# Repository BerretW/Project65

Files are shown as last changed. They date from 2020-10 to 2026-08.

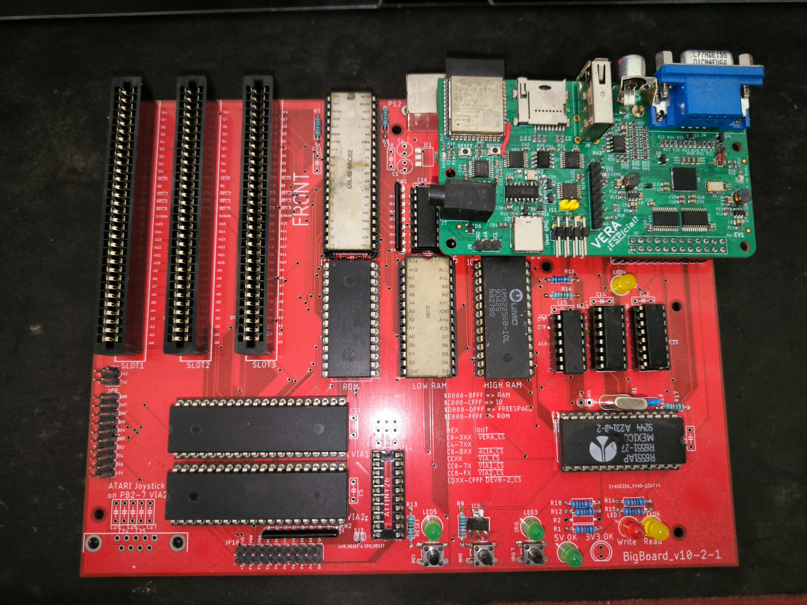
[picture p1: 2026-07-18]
images/V10-2-1_Vera2.jpg

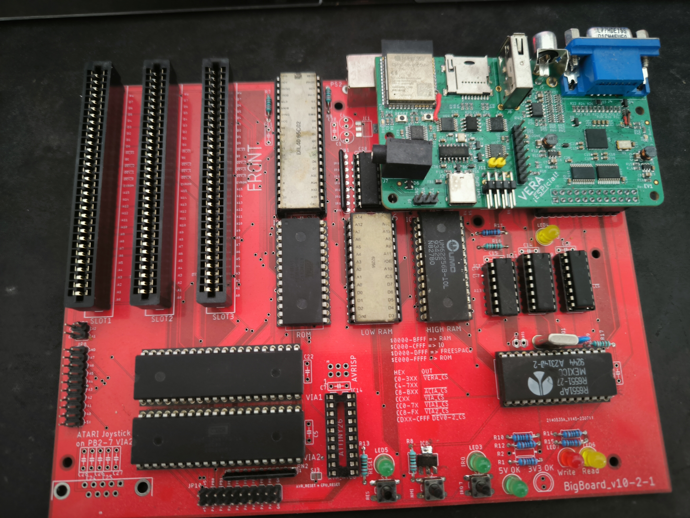
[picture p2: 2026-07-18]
images/V10-2-1_Vera.jpg

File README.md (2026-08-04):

# Project65 — SBC 65C02 IRQ BigBoard

A fully custom **W65C02-based single-board computer** featuring an 8-priority-level IRQ subsystem, three ISA-8 expansion slots, a PS/2 keyboard interface, RS-232 serial port, and a complete firmware stack — including an interactive OS with a RAM-disk filesystem. Accompanied by a **full-featured Rust emulator** with a terminal UI and an **FPGA VGA + audio controller** (`APARTS_BUS`) for Intel MAX 10.

---

## Features

- **CPU:** W65C02S @ up to 8 MHz (jumper-selectable from 32 MHz main oscillator)
- **Memory:** 64 KB total — 32 KB lower RAM + 32 KB upper RAM + 8 KB EEPROM ROM
- **Serial:** R6551 ACIA with a 1.8432 MHz crystal for accurate baud rates
- **Parallel I/O:** 2× W65C22S VIA controllers (keyboard polling + parallel port)
- **PS/2 Keyboard:** ATtiny26 co-processor bridge
- **Interrupt system:** 74HC148 priority encoder + 74HC574 latch — 8 prioritized IRQ lines + NMI
- **Expansion:** 3× ISA-8 slots (TMS9918A, GameDuino, APARTS_BUS FPGA card)
- **FPGA video/audio:** `APARTS_BUS` — VGA 640×480, external SRAM framebuffer, font RAM, 4-ch DDS/ADSR → PCM5102A I²S
- **Firmware:** Two build targets — minimal bootloader and full AppartusOS
- **Emulator:** Rust TUI emulator (`p65emu`) with cycle-accurate peripherals

---

## Repository Structure

```text
Project65/
├── Eagle/              # PCB schematics and board layouts (Eagle CAD)
│   ├── SBC_65C02_IRQ_BigBoard_v10-2-1.*
│   ├── EXP_TMS9918A_V1.*
│   └── EXP_GameDuino_V1.*
├── Firmware/           # 65C02 firmware (cc65 / ca65 toolchain)
│   ├── src/            # Assembly + C sources (drivers, OS, shell, EWOZ)
│   │   └── os/         # AppartusOS modules
│   ├── config/         # ld65 linker configurations
│   ├── output/         # Build artifacts (*.bin, *.map)
│   ├── build_minimal.bat
│   └── build_appartus.bat
├── emulator/           # Rust emulator (p65emu)
│   └── src/            # cpu, bus, ram, rom, acia, via, irq_latch, tui
├── aprts_vga/          # APARTS_BUS FPGA RTL (Verilog) + Quartus + sim
│   ├── aprts_bus.v     # Top-level 6502 bus interface
│   ├── vga_timing.v    # VGA 640×480 @ 60 Hz timing (25 MHz)
│   ├── vga_video_gen.v # Graphics/text pixel path + font RAM
│   ├── sram_controller.v
│   ├── aprts_audio.v   # 4-ch DDS/ADSR + I²S (PCM5102A)
│   ├── 10M02_test.qsf  # Quartus project (MAX 10 10M02SCE144C8G)
│   └── sim/            # ModelSim / Icarus testbenches
├── GAL/                # Glue logic (PLD)
├── tools/
│   ├── uploader.py     # Python/tkinter firmware uploader (COM or TCP)
│   ├── aprts_vga/      # 6502 demo for FPGA VGA
│   ├── audio/          # Audio driver + samples (ca65)
│   └── …               # hello, mem_mon, vera_test, vga_test, …
└── CLAUDE.md           # Full hardware reference (address map, ICs, bugs)
```

---

## Hardware Overview

| Reference | Part | Description |
| --- | ---- | --- |
| IC4 | W65C02SP | Main CPU (CMOS 65C02, DIP-40) |
| IC5 | AT28C64B | 8 KB EEPROM — ROM (`$E000–$FFFF`) |
| IC6 | 62256 | 32 KB SRAM — lower RAM (`$0000–$7FFF`) |
| IC7 | 62256 | 32 KB SRAM — upper RAM (`$8000–$BFFF`) |
| IC8 | DS1233 | Power-on reset supervisor |
| IC16 | W65C22S6TP | VIA #2 (`$CC80`) — parallel port JP8, generates **IRQ1** |
| IC18 | W65C22S6TP | VIA #1 (`$CC00`) — ATtiny26 keyboard bridge, generates **NMI** |
| IC19 | R6551 | ACIA serial (`$C800–$CBFF`) |
| IC14 | ATtiny26 | PS/2 keyboard co-processor (PB3=CLK, PB4=DATA) |
| U$1 | MCP2221A | USB-C ↔ UART/I²C bridge |
| IC9/IC11 | 74HCT139N | Two-stage address decoder |
| IC17 | 74HC148N | 8→3 priority IRQ encoder |
| IC27 | 74HC574N | IRQ status latch (readable at `$C480`) |
| QG1 | 32 MHz | Main system oscillator |
| Q1 | 1.8432 MHz | ACIA baud-rate crystal |
| X1–X3 | ISA-8 slots | Three 8-bit ISA expansion slots |

### ISA Expansion Cards

| Card | Description |
| ---- | --- |
| `EXP_TMS9918A_V1` | TMS9918A video card |
| `EXP_GameDuino_V1` | GameDuino graphics card |
| **APARTS_BUS** (`aprts_vga/`) | FPGA VGA 640×480 + external SRAM + 4-ch audio (MAX 10) |

---

## Address Map

```text
$0000–$7FFF   IC6 SRAM — lower 32 KB       (!CS = A15 low)
$8000–$BFFF   IC7 SRAM — upper 32 KB       (!CS = !HRAM_CS)
$C000–$C3FF   VERA / ISA video             (!VERA_CS)
$C400–$C7FF   IRQ latch                    read $C480–$C4FF / ack $C400–$C47F
$C800–$CBFF   ACIA R6551
$CC00–$CC7F   VIA1 (IC18) — keyboard/NMI
$CC80–$CCFF   VIA2 (IC16) — parallel/IRQ1
$CD00–$CDFF   ISA DEV0
$CE00–$CEFF   ISA DEV1
$CF00–$CFFF   ISA DEV2   ← typical APARTS_BUS decode (tools use $CF00 / $CE00)
$D000–$DFFF   ISA extended
$E000–$FFFF   EEPROM ROM (8 KB)
```

### IRQ Priority Table

| Level | Signal | Source |
| ----- | --- | --- |
| 0 (highest) | IRQ0 | R6551 ACIA |
| 1 | IRQ1 | VIA2 (IC16, `$CC80`) |
| 2–6 | IRQ2–6 | ISA slots |
| 7 (lowest) | IRQ7 | Button S1 |
| — | **NMI** | **VIA1 (IC18, `$CC00`)** |

---

## APARTS_BUS — FPGA VGA & Audio (`aprts_vga/`)

RTL controller for the 6502/ISA bus: **VGA output**, **external SRAM framebuffer (up to 512 KB / 19-bit address)**, **internal font RAM**, and a **4-channel synthesizer** driving a **PCM5102A** over I²S.

Detailed programmer manual: [`aprts_vga/README.md`](aprts_vga/README.md).

### Target & RTL modules

| Item | Value |
| ---- | ----- |
| FPGA | Intel **MAX 10** — `10M02SCE144C8G` |
| Quartus project | `aprts_vga/10M02_test.qsf` |
| Top entity | `aprts_bus` |
| Pixel clock | **25 MHz** — VGA **640×480 @ 60 Hz** |

| File | Module | Role |
| ---- | --- | ---- |
| `aprts_bus.v` | `aprts_bus` | Top: 4-bit port decode, CPU R/W, submodule wiring |
| `vga_timing.v` | `vga_timing` | H/V counters, HSYNC/VSYNC, `video_on` |
| `vga_video_gen.v` | `vga_video_gen` | Graphics/text RGB, font RAM (128×8 = 1024 B), cursor blink |
| `sram_controller.v` | `sram_controller` | CPU ↔ VGA arbiter, hardware clear engine |
| `aprts_audio.v` | `aprts_audio` | 4-ch DDS + ADSR, I²S (`pcm_bck` / `pcm_din` / `pcm_lrck`) |

### External interfaces (from `aprts_bus`)

```text
6502 bus:   n_reset, n_mem_w, n_mem_r, lv_cs, clk, lv_addr[3:0], lv_data[7:0]
VGA:        red[2:0], green[2:0], blue[2:0], hsync, vsync
SRAM:       sram_addr[18:0], sram_data[7:0], sram_ce_n, sram_oe_n, sram_we_n
Audio I²S:  pcm_bck, pcm_din, pcm_lrck, pcm_sck
```

### Register map (ports `$0`–`$F` relative to card base)

| Port | Write | Read |
| ---- | ----- | ---- |
| `$0` | Background color RGB332 | `reg_bg_color` |
| `$1` | Address / cursor hi (`addr_hi`) | same |
| `$2` | Address mid (`addr_mid`) | same |
| `$3` | Address lo (`addr_lo`) | same |
| `$4` | Data → SRAM / font / text cell | Data ← SRAM / font |
| `$5` | Audio register index (`0x00`–`0x17`) | current index |
| `$6` | Audio register data (index auto-inc) | selected audio reg |
| `$D` | Mode | current mode |
| `$F` | Start SRAM clear (any value) | status: bit0 = `addr_ready` |

CPU SRAM pointer is 19-bit: `{addr_hi[2:0], addr_mid, addr_lo}`. After each write to port `$4` (except font mode `$0D`) the address **auto-increments**.

**Background / pixel color:** `[7:5]` R, `[4:2]` G, `[1:0]` B (expanded to 3 bits in HW).

### Mode register (`$D`)

| Value | Behavior |
| ----- | --- |
| `$00`–`$0C` | Graphics — linear framebuffer from external SRAM |
| `$01` | Text 80×60, static cursor |
| `$02` | Text 80×60, blinking cursor (~2 Hz) |
| `$0D` | Font edit — R/W internal `font_mem` via port `$4` |
| `$0E` | Hardware logic reset (counters, audio, registers) |
| `$0F` | Blank screen (force black) |

Text buffer uses the first **4800** bytes of SRAM (`80×60`, `$0000`–`$12BF`). Font RAM: **128 characters × 8 rows**.

### SRAM clear & status (`$F`)

- **Write:** starts hardware fill of external SRAM with zeros (clear range through `$4AFFF` in RTL).
- **Read bit 0 (`addr_ready`):** `1` = ready for CPU access; `0` = clear/write busy. Poll before further writes.

### Audio (ports `$5` / `$6`)

Four independent DDS channels mixed to I²S (PCM5102A). Sample rate in driver notes: **~48.828 kHz**.

Per channel (base offsets for ch0; +3 per channel for ch1–3):

| Index | Register |
| ----- | --- |
| `+0` / `+1` | Frequency lo / hi |
| `+2` | Volume |
| `$0C`–`$0F` | Control: wave `[2:0]`, ADSR enable `[3]`, gate/note-on `[4]` |
| `$10`–`$17` | ADSR Attack/Decay and Sustain/Release pairs |

Waveforms: `0` square, `1` triangle, `2` saw, `3` sine, `4` trapezoid. Writing `$6` auto-increments the audio index.

### Simulation (`aprts_vga/sim/`)

| File | Purpose |
| ---- | --- |
| `tb_aprts_bus.v` | Integration test of full `aprts_bus` |
| `tb_vga_timing.v` | VGA timing unit test |
| `tb_aprts_audio.v` | Audio registers + I²S clocks |
| `sram_model.v` | Behavioral 512 KB SRAM |
| `run_msim.bat` / `run_msim.do` | ModelSim / Questa-Intel |
| `run_iverilog.bat` | Icarus Verilog |

```bat
cd aprts_vga\sim
run_msim.bat
rem or: run_iverilog.bat
```

See [`aprts_vga/sim/README.md`](aprts_vga/sim/README.md).

### Host-side tools

| Path | Description |
| ---- | --- |
| `tools/aprts_vga/` | ca65 demo (`demo.asm`) — base often `$CF00` |
| `tools/audio/` | Audio includes (`audio.inc65`) and samples — ports `$5`/`$6` on card base |

Exact ISA slot base (`$CD00` / `$CE00` / `$CF00`) depends on which DEV chip-select the card is wired to.

---

## Firmware

### Prerequisites

- [cc65](https://cc65.github.io/) toolchain (`cc65`, `ca65`, `ld65`) on `PATH`

### Minimal Build

ACIA serial + EWOZ (WozMon) monitor + serial bootloader (loads to `$6000`).  
No keyboard, VDP, SPI, SD, GameDuino, or SAA1099 dependencies.

```bat
cd Firmware
build_minimal.bat
```

Output: `Firmware/output/MIN_ROM.bin` (8 KB, write to EEPROM IC5)

### AppartusOS Build

Full OS: ACIA + EWOZ (`MON` command) + Intel HEX loader + interactive shell + RAM-disk FS.

```bat
cd Firmware
build_appartus.bat
```

Output: `Firmware/output/APPARTUS_OS.bin` (8 KB, write to EEPROM IC5)

### AppartusOS Shell Commands

```text
HELP / ?                   — help
VER                        — OS version
DIR                        — list RAM-disk files
FREE                       — show free space
FORMAT                     — reinitialize RAM disk (requires Y confirmation)
LOAD                       — receive Intel HEX via ACIA
SAVE <name> <addr> <size>  — save RAM region to RAM disk (hex addresses)
DEL  <name>                — delete file
RUN  <name>                — execute file (program can RTS back to shell)
MON                        — EWOZ / WozMon monitor
RESET                      — soft reset ($FF00)
```

### RAM Disk Layout (`$6000–$BFFF`, 24 KB)

```text
$6000–$600F   Header: "APOS" + num_files + free_ptr
$6010–$610F   Directory: 16 entries × 16 bytes
              +0 name[8]  +8 load_addr  +10 size  +12 flags  +13 stor_addr
$6110–$BFFF   File data (~24 KB usable)
```

### Firmware Memory Map (ROM, `$E000–$FFFF`)

```text
ZP:      $0000–$00FF   (zero page; cc65 $00–$1F, EWOZ $24–$30, ihex $38–$3E, OS $40–$4E)
RAM:     $0200–$5FFF   (working RAM; stack at $5FFF growing down)
ROM:     $E000–$FFFF   (EEPROM, fill $FF)
JMPTBL:  $FF00         (BIOS-style jump table)
VECTORS: $FFFA         (NMI / RESET / IRQ vectors)
```

---

## Emulator — p65emu

A cycle-accurate Rust emulator with a ratatui terminal UI.

### Build Requirements

- [Rust toolchain](https://rustup.rs/) (stable)

### Build & Run

```sh
cargo run --manifest-path emulator/Cargo.toml -- [ROM.bin] [-s SPEED_HZ] [-p TCP_PORT]
```

| Flag | Default | Description |
| ---- | --- | --- |
| `ROM.bin` | — | ROM image to load at `$E000` |
| `-s SPEED_HZ` | `1000000` | Emulation speed in Hz |
| `-p TCP_PORT` | `6551` | TCP serial port (0 = disabled) |
| `--family` | `HCT` | Logic family timing model (`LS`, `ALS`, `HCT`, `HC`, `AC`, `ACT`) |

### Emulated Components

| Module | Hardware |
| --- | --- |
| `cpu.rs` | W65C02 — fetch/decode/execute + NMI/IRQ |
| `ram.rs` | IC6 + IC7 SRAM |
| `rom.rs` | 8 KB EEPROM |
| `acia.rs` | R6551 — TX/RX queues shared with TUI and TCP |
| `via.rs` | VIA1 (`$CC00`) + VIA2 (`$CC80`) — T1/T2 timers |
| `irq_latch.rs` | 74HC574 latch + 74HC148 encoder |
| `tms9918a.rs` | TMS9918A video (minifb window) |
| `saa1099.rs` | SAA1099 audio (rodio) |

### TUI Keyboard Shortcuts

| Key | Action |
| --- | --- |
| F2 | Single step |
| F3 | Run / Pause |
| F4 | Reset CPU |
| F5–F9 | Speed: 1K / 10K / 100K / 1M / MAX Hz |
| +/- | Speed ×2 / ÷2 |
| Tab | Memory view: ZP / RAM / HiRAM / I/O / ROM / Addr |
| Shift+Tab | Right panel: CPU / VIA1 / VIA2 / ACIA / IRQ |
| PgUp/PgDn | Scroll memory |
| Shift+Pg | Scroll terminal |
| Ctrl+O | File browser — load ROM or RAM image |
| Ctrl+G | Jump to hex address in memory dump |
| Ctrl+M | Edit byte at address |
| Ctrl+R | Edit CPU registers (A/X/Y/SP/PC/P) |
| F10 / Ctrl+Q | Quit |

The TCP serial port (default `127.0.0.1:6551`) allows PuTTY, netcat, or `uploader.py` to connect as if it were real hardware.

---

## Tools

### tools/uploader.py

Python/tkinter GUI for uploading firmware to the real board or the emulator.

**Dependencies:**

```sh
pip install pyserial
```

**Connection modes:**

- **COM port** — real hardware (19200 Bd, 8N1)
- **TCP** — emulator (`127.0.0.1:6551`)

**Bootloader protocol:**

| Command | Action |
| --- | --- |
| `w` | Raw binary upload — exactly 8192 bytes → `$6000–$7FFF` |
| `h` | Intel HEX upload (any address) |
| `s` | Jump to `$6000` (run program) |
| `m` | Enter EWOZ / WozMon monitor |
| `^R` (`$12`) | Soft-restart bootloader |

### Other tools

| Path | Description |
| ---- | --- |
| `tools/aprts_vga/` | APARTS_BUS VGA demo for AppartusOS |
| `tools/audio/` | 4-channel FPGA audio driver and samples |
| `tools/hello/` | Sample user program |
| `tools/ihex_gen.py` | Intel HEX helper |
| `tools/espi_update_fpga.py` | FPGA update helper |
| `tools/vera_test/`, `tools/vga_test/` | Video experiments |

---

## Typical Workflow

```sh
# 1. Build firmware
cd Firmware && build_appartus.bat

# 2. Start emulator
cargo run --manifest-path emulator/Cargo.toml -- Firmware/output/APPARTUS_OS.bin

# 3. In emulator terminal — send a program via Intel HEX
> LOAD
  (paste or send .hex file via uploader.py over TCP)

# 4. Save and run
> SAVE HELLO 6090 0100
> DIR
> RUN HELLO
```

FPGA RTL / sim workflow:

```bat
cd aprts_vga\sim
run_msim.bat
```

---

## Known Issues

| # | Status | Description |
| - | --- | --- |
| 1 | ✅ Fixed | `_nmi_init` in `utils.asm` — NMI Timer1 initialization correctly configures VIA1 (IC18) at $CC00 |
| 2 | ✅ Fixed | NMI ISR correctly reloads VIA1 (IC18) T1 counter — verified in `interrupts.asm:19` |
| 3 | ✅ Fixed | PS/2 keyboard driver in `pckybd.asm:25–28` — now correctly reads from VIA1 (IC18, ATtiny26) |
| 4 | ✅ Fixed | `VDP_MODE0 = $C000` — correctly placed in ISA I/O space, no longer conflicts with IC6 RAM |

All critical hardware bugs have been resolved.

---

## Hardware Files

| File | Description |
| ---- | --- |
| `Eagle/SBC_65C02_IRQ_BigBoard_v10-2-1.csv` | Current BOM / netlist |
| `Eagle/SBC_65C02_IRQ_BigBoard_v9-1-3.sch` | Main schematic (Eagle) |
| `Eagle/SBC_65C02_IRQ_BigBoard_v9-1-3.brd` | Main PCB layout (Eagle) |
| `Eagle/EXP_TMS9918A_V1.sch/.brd` | TMS9918A ISA video card |
| `Eagle/EXP_GameDuino_V1.sch/.brd` | GameDuino ISA graphics card |
| `aprts_vga/*.v` | APARTS_BUS FPGA RTL (VGA + SRAM + audio) |
| `aprts_vga/10M02_test.qsf` | Quartus pinout / project for MAX 10 |

Full hardware documentation (address decoding logic, IC cross-reference, IRQ system) is in [`CLAUDE.md`](CLAUDE.md).  
FPGA register-level docs: [`aprts_vga/README.md`](aprts_vga/README.md).

---

## License

See [`Firmware/LICENSE`](Firmware/LICENSE).

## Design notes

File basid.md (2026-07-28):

# P65 BASIC — syntax a manuál

Tento dokument popisuje syntaxi a chování BASICu implementovaného v [Firmware/src/os/appartus_basic.asm](Firmware/src/os/appartus_basic.asm).

## 1. Co je to za BASIC?

P65 BASIC je minimalistický line-oriented BASIC pro Project65 SBC.

- pracuje s celými čísly, 16bitovými a znaménkovými
- používá proměnné A až Z
- program je ukládán do paměti RAM jako seznam řádků
- podporuje direktivní příkazy i programové příkazy

## 2. Základní pravidla

### 2.1 Čísla

- desetinná čísla nejsou podporována
- všechny hodnoty jsou 16-bitové signed integery
- záporná čísla jsou podporována
- hexadecimální konstanta se zapisuje s předponou `$`

Příklady:

- `10`
- `-5`
- `$1F`
- `$FF00`

### 2.2 Proměnné

Proměnné jsou pojmenovány jedním písmenem `A` až `Z`.

Příklady:

- `A = 10`
- `B = A + 5`

### 2.3 Programové řádky

Každý řádek programu začíná číslem řádku:

```basic
10 PRINT "Ahoj"
20 END
```

Řádkové číslo může být zadáno jako desetinné číslo nebo hexadecimální konstanta.

## 3. Direktivní příkazy

Tyto příkazy se spouštějí přímo z promptu, nikoli jako programové řádky.

### 3.1 NEW

Smaže celý program.

```basic
NEW
```

### 3.2 LIST

Vypíše uložený program.

```basic
LIST
```

### 3.3 RUN

Spustí program od prvního řádku.

```basic
RUN
```

### 3.4 SAVE

Uloží program do RAMDisku pod jméno.

```basic
SAVE "HELLO"
```

- název může mít maximálně 8 znaků
- uložení se provádí do RAMDisku

### 3.5 LOAD

Načte program z RAMDisku.

```basic
LOAD "HELLO"
```

### 3.6 BYE

Vrátí se zpět do shellu OS.

```basic
BYE
```

## 4. Programové příkazy

### 4.1 REM

Komentář. Vše za `REM` je ignorováno.

```basic
10 REM Toto je komentář
20 PRINT 1
```

### 4.2 PRINT

Vypíše text nebo hodnotu výrazu.

```basic
10 PRINT "HELLO"
20 PRINT A
30 PRINT 10 + 5
```

Více položek lze oddělit znakem `;` nebo `,`.

```basic
10 PRINT "A=", A
20 PRINT 1; 2; 3
```

- `;` znamená bez nového řádku mezi položkami
- `,` vypíše mezery mezi položkami

### 4.3 INPUT

Načte vstup z konzole a uloží do proměnné.

```basic
10 INPUT A
```

Volitelně lze zadat prompt:

```basic
10 INPUT "Zadej cislo: ", A
```

### 4.4 Přiřazení

Podporováno je `LET` i implicitní přiřazení.

```basic
10 LET A = 10
20 B = A + 5
```

### 4.5 IF ... THEN

Podmínka se vyhodnotí a pokud je pravdivá, skočí na zadaný řádek.

```basic
10 IF A > 0 THEN 30
20 PRINT "NE"
30 PRINT "ANO"
```

Poznámka: `THEN` je nepovinný v implementaci, ale doporučený zápis je s ním.

### 4.6 FOR ... TO ... STEP ...

Smyčka s počítadlem.

```basic
10 FOR A = 1 TO 5
20 PRINT A
30 NEXT
```

Volitelný krok:

```basic
10 FOR A = 0 TO 10 STEP 2
20 PRINT A
30 NEXT
```

### 4.7 NEXT

Konec smyčky `FOR`.

```basic
10 FOR A = 1 TO 3
20 PRINT A
30 NEXT
```

### 4.8 WHILE ... WEND

Podmíněná smyčka.

```basic
10 A = 0
20 WHILE A < 3
30 PRINT A
40 A = A + 1
50 WEND
```

### 4.9 GOTO

Nepodmíněný skok na jiný řádek.

```basic
10 GOTO 30
20 PRINT "Tento řádek se nepřeskočí"
30 PRINT "Skok funguje"
```

### 4.10 GOSUB / RETURN

Volání podprogramu.

```basic
10 GOSUB 30
20 END
30 PRINT "Podprogram"
40 RETURN
```

### 4.11 END

Ukončí běh programu.

```basic
10 PRINT "Konec"
20 END
```

### 4.12 POKE

Zapíše hodnotu do paměti na zadanou adresu.

```basic
10 POKE 40960, 255
```

## 5. Výrazy

### 5.1 Operátory

Podporované operátory:

- `+` sčítání
- `-` odčítání / unární negace
- `*` násobení
- `/` dělení

### 5.2 Porovnání

Podporované porovnání:

- `=` rovnost
- `<>` nerovnost
- `<` menší
- `>` větší
- `<=` menší nebo rovno
- `>=` větší nebo rovno

Porovnání vrací `0` pro nepravdu a `1` pro pravdu.

### 5.3 Závorky

```basic
10 PRINT (2 + 3) * 4
```

### 5.4 PEEK

Načte bajt z paměti na dané adrese.

```basic
10 PRINT PEEK(1024)
```

Poznámka: `PEEK` vrací 8bitovou hodnotu a horní byte je nulový.

## 6. Priorita operátorů

Priorita je následující (od nejnižší po nejvyšší):

1. porovnání
2. `+` a `-`
3. `*` a `/`
4. unární `-` a primární výrazy

## 7. Chyby a hlášky

Při chybě BASIC vypíše jednu z těchto hlášek:

- `?SYNTAX ERROR` — špatný syntax
- `?UNDEFINED LINE` — neexistující řádek pro `GOTO`, `GOSUB`, `IF`
- `?FOR OVF` — přetečení zásobníku `FOR`
- `?NEXT WO FOR` — `NEXT` bez odpovídajícího `FOR`
- `?WHILE OVF` — přetečení zásobníku `WHILE`
- `?WEND WO WHILE` — `WEND` bez odpovídajícího `WHILE`
- `?GOSUB OVF` — přetečení zásobníku `GOSUB`
- `?RET WO GOSUB` — `RETURN` bez `GOSUB`
- `?DIV/0` — dělení nulou
- `?PROG FULL` — programová paměť je plná
- `?Save err.` — chyba při ukládání
- `?Not found.` — soubor nenalezen při `LOAD`

## 8. Příklad programu

```basic
10 REM Jednoduchý program
20 INPUT "Zadej cislo: ", A
30 IF A > 0 THEN 60
40 PRINT "Cislo je zaporne"
50 GOTO 70
60 PRINT "Cislo je kladne"
70 END
```

## 9. Praktické poznámky

- BASIC je určený pro jednoduché skripty a testování
- není to plnohodnotný moderní BASIC
- je vhodný pro práci s pamětí, jednoduchými rutinnami a obsluhou vstupu/výstupu
- programy jsou uloženy jako textové řádky s číslem řádku a nulovým terminátorem

## 10. Shrnutí

Nejčastější konstrukce jsou:

```basic
10 PRINT "Text"
20 INPUT A
30 IF A > 0 THEN 50
40 GOTO 60
50 FOR A = 1 TO 5
60 NEXT
70 WHILE A < 3
80 WEND
90 END
```

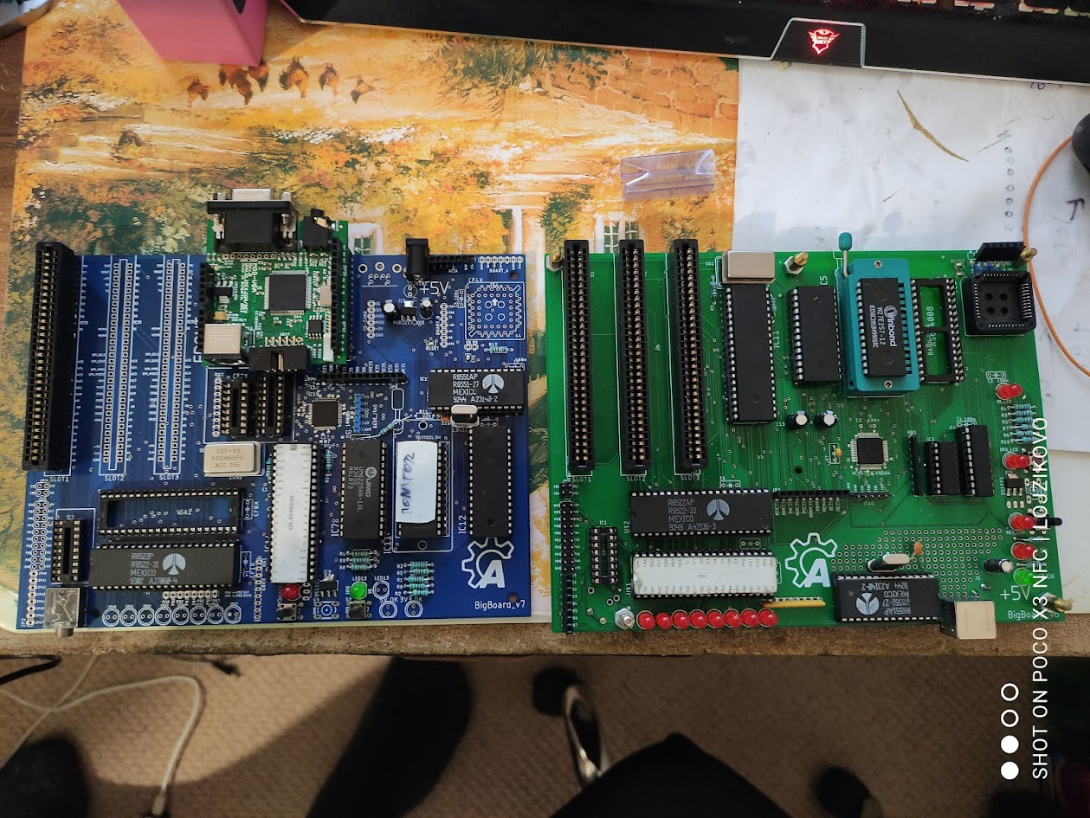
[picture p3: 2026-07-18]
images/V6_vs_V7.jpg

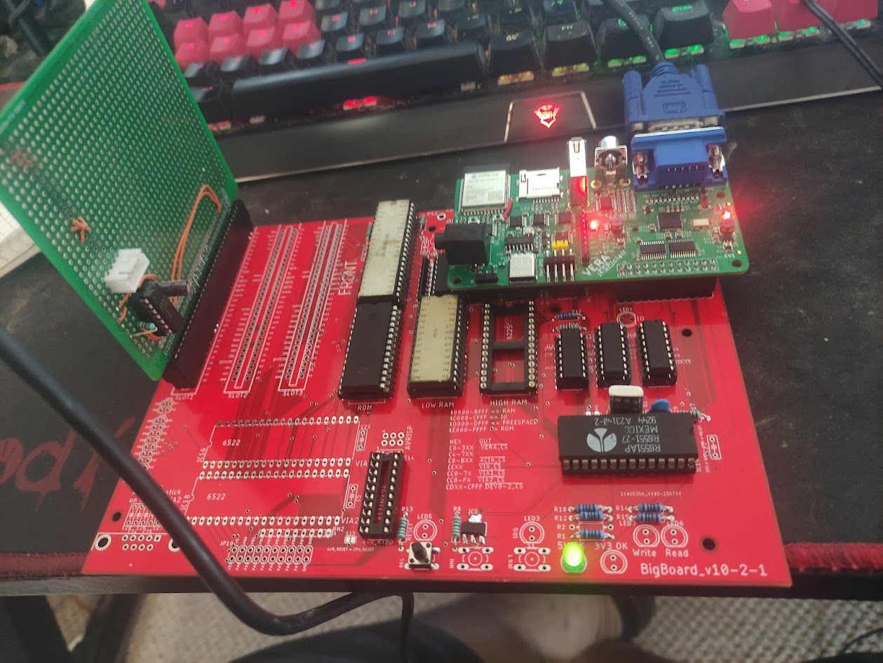
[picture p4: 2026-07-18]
images/V10-2-1_partial.jpg

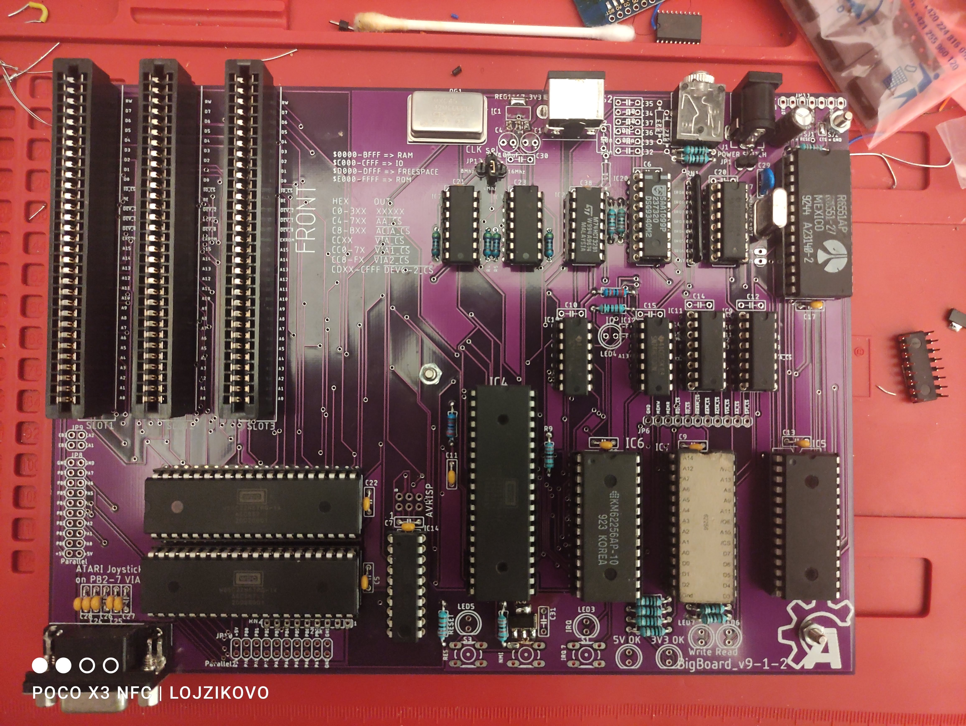
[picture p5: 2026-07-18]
images/V9-1-2.jpg

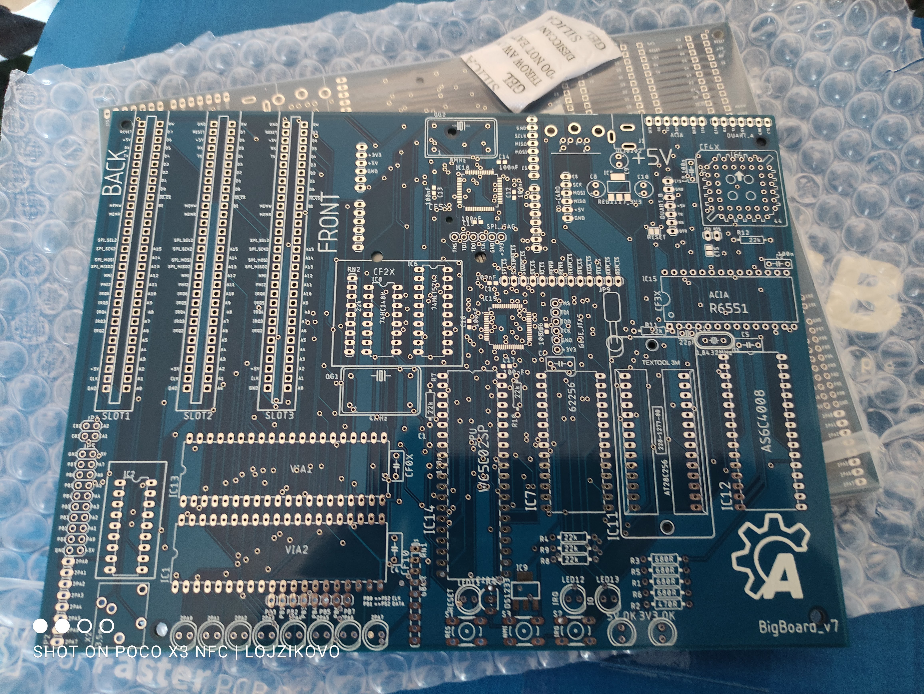
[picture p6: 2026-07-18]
images/V7_blank.jpg

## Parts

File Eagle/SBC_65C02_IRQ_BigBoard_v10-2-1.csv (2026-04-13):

Part | Value | Device | Package | Description | MF | MPN | OC_FARNELL | OC_NEWARK | POPULARITY | PROD_ID | SPICEPREFIX
C1 | 10uF | CPOL-EUE2.5-5 | E2,5-5 | POLARIZED CAPACITOR, European symbol |  |  |  |  | 16 |  | C
C2 |  | C-EU050-035X075 | C050-035X075 | CAPACITOR, European symbol |  |  |  |  | 2 |  | C
C3 |  | CPOL-EUE2.5-5 | E2,5-5 | POLARIZED CAPACITOR, European symbol |  |  |  |  | 16 |  | C
C4 | 100uF | CPOL-EUE2.5-5 | E2,5-5 | POLARIZED CAPACITOR, European symbol |  |  |  |  | 16 |  | C
C5 |  | C-EU050-025X075 | C050-025X075 | CAPACITOR, European symbol |  |  |  |  | 29 |  | C
C6 |  | C-EU050-025X075 | C050-025X075 | CAPACITOR, European symbol |  |  |  |  | 29 |  | C
C7 |  | C-EU050-025X075 | C050-025X075 | CAPACITOR, European symbol |  |  |  |  | 29 |  | C
C8 |  | C-EU050-025X075 | C050-025X075 | CAPACITOR, European symbol |  |  |  |  | 29 |  | C
C9 |  | C-EU050-025X075 | C050-025X075 | CAPACITOR, European symbol |  |  |  |  | 29 |  | C
C10 |  | C-EU050-025X075 | C050-025X075 | CAPACITOR, European symbol |  |  |  |  | 29 |  | C
C11 |  | C-EU050-025X075 | C050-025X075 | CAPACITOR, European symbol |  |  |  |  | 29 |  | C
C12 |  | C-EU050-025X075 | C050-025X075 | CAPACITOR, European symbol |  |  |  |  | 29 |  | C
C13 |  | C-EU050-025X075 | C050-025X075 | CAPACITOR, European symbol |  |  |  |  | 29 |  | C
C14 |  | C-EU050-025X075 | C050-025X075 | CAPACITOR, European symbol |  |  |  |  | 29 |  | C
C15 |  | C-EU050-025X075 | C050-025X075 | CAPACITOR, European symbol |  |  |  |  | 29 |  | C
C16 |  | C-EU050-025X075 | C050-025X075 | CAPACITOR, European symbol |  |  |  |  | 29 |  | C
C17 |  | C-EU050-025X075 | C050-025X075 | CAPACITOR, European symbol |  |  |  |  | 29 |  | C
C18 |  | C-EU050-025X075 | C050-025X075 | CAPACITOR, European symbol |  |  |  |  | 29 |  | C
C20 |  | C-EU050-025X075 | C050-025X075 | CAPACITOR, European symbol |  |  |  |  | 29 |  | C
C21 |  | C-EU050-025X075 | C050-025X075 | CAPACITOR, European symbol |  |  |  |  | 29 |  | C
C22 |  | C-EU050-025X075 | C050-025X075 | CAPACITOR, European symbol |  |  |  |  | 29 |  | C
C23 |  | C-EU050-025X075 | C050-025X075 | CAPACITOR, European symbol |  |  |  |  | 29 |  | C
C24 | 1n | C-EU050-025X075 | C050-025X075 | CAPACITOR, European symbol |  |  |  |  | 29 |  | C
C25 | 1n | C-EU050-025X075 | C050-025X075 | CAPACITOR, European symbol |  |  |  |  | 29 |  | C
C26 | 1n | C-EU050-025X075 | C050-025X075 | CAPACITOR, European symbol |  |  |  |  | 29 |  | C
C27 | 1n | C-EU050-025X075 | C050-025X075 | CAPACITOR, European symbol |  |  |  |  | 29 |  | C
C28 | 1n | C-EU050-025X075 | C050-025X075 | CAPACITOR, European symbol |  |  |  |  | 29 |  | C
C29 |  | C-EU050-025X075 | C050-025X075 | CAPACITOR, European symbol |  |  |  |  | 29 |  | C
C30 |  | C-EU050-025X075 | C050-025X075 | CAPACITOR, European symbol |  |  |  |  | 29 |  | C
C38 |  | C-EU050-025X075 | C050-025X075 | CAPACITOR, European symbol |  |  |  |  | 29 |  | C
IC1 | REG1117_3V3 | REG1117 | SOT223 | 800mA and 1A Low Dropout (LDO) Positive Regulator |  | REG1117 | 1097566 | 14P6981 | 49
IC2 | 74HC74N | 74HC74N | DIL14 | Dual D type positive edge triggered FLIP FLOP, preset and clear |  |  |  |  | 0
IC3 | 74HC74N | 74HC74N | DIL14 | Dual D type positive edge triggered FLIP FLOP, preset and clear |  |  |  |  | 0
IC4 | W65C02SP | W65C02SP | DIL40 | Western Digital Version
IC5 | 28C64AP | 28C64AP | DIL28-6 | CMOS EEPROM |  | AT28C64B-15PU | 1631144 | 96K6557 | 0
IC6 | 62256 | 62256P | DIL28-6 | MEMORY |  |  | unknown | unknown | 1
IC7 | 62256 | 62256P | DIL28-6 | MEMORY |  |  | unknown | unknown | 1
IC8 | DS1233 | DS1233SOT223 | SOT223
IC9 | 74HCT139N | 74HCT139N | DIL16 | Dual 2-line to 4-line DECODER/DEMULTIPLEXER |  |  |  |  | 0
IC10 | 74AC00N | 74AC00N | DIL14 | Quad 2-input NAND gate |  |  |  |  | 0
IC11 | 74HCT139N | 74HCT139N | DIL16 | Dual 2-line to 4-line DECODER/DEMULTIPLEXER |  |  |  |  | 0
IC12 | 74AC00N | 74AC00N | DIL14 | Quad 2-input NAND gate |  |  |  |  | 0
IC14 | ATTINY26-16PU | ATTINY26-16PU | DIL20 | 8-bit AVR tiny Microcontroller
IC16 | VIA1 | W65C22S6TP | DIL40 | W65C22 by WDC
IC17 | 74HC148N | 74HC148N | DIL16 | 10-line to 4-line and 8-line to 3-line PRIORITY ENCODER |  |  |  |  | 0
IC18 | VIA2 | W65C22S6TP | DIL40 | W65C22 by WDC
IC19 | R6551 | R6551 | DIP-28 | Rockwell R6551 ACIA
IC21 | 74AC32N | 74AC32N | DIL14 | Quad 2-input OR gate |  |  |  |  | 0
IC27 | 74HC574N | 74HC574N | DIL20 | 8-bit D type FLIP FLOP bus driver |  |  |  |  | 0
J1 | DCJ0202 | DCJ0202 | DCJ0202 | DC POWER JACK |  |  | unknown | unknown | 17
J2 | AVR_SPI_PROG_3X2NS | AVR_SPI_PROG_3X2NS | 2X3-NS | AVR ISP 6 Pin
J3 |  | DB9MALE | DB9_MALE | DB9 Connector |  |  |  |  |  | CONN-09904
J4 |  | USB_C2-LAYER | USB-C-16P | USB Type C 16Pin Connector |  |  |  |  |  | CONN-14122
JP1 |  | PINHD-1X2 | 1X02 | PIN HEADER |  |  |  |  | 98
JP2 |  | PINHD-1X1 | 1X01 | PIN HEADER |  |  |  |  | 64
JP3 |  | PINHD-1X1 | 1X01 | PIN HEADER |  |  |  |  | 64
JP4 |  | PINHD-1X1 | 1X01 | PIN HEADER |  |  |  |  | 64
JP5 |  | PINHD-1X1 | 1X01 | PIN HEADER |  |  |  |  | 64
JP6 |  | PINHD-2X12 | 2X12 | PIN HEADER |  |  |  |  | 3
JP8 | Parallel | PINHD-2X10 | 2X10 | PIN HEADER |  |  |  |  | 7
JP9 | Timer_OUT | PINHD-2X2 | 2X02 | PIN HEADER |  |  |  |  | 0
JP10 | Parallel2 | PINHD-2X10 | 2X10 | PIN HEADER |  |  |  |  | 7
JP11 |  | PINHD-1X7 | 1X07 | PIN HEADER |  |  |  |  | 0
JP12 |  | PINHD-1X2 | 1X02 | PIN HEADER |  |  |  |  | 98
JP13 |  | PINHD-1X1 | 1X01 | PIN HEADER |  |  |  |  | 64
LED1 |  | LED5MM | LED5MM | LED |  |  |  |  | 93
LED2 |  | LED5MM | LED5MM | LED |  |  |  |  | 93
LED3 |  | LED5MM | LED5MM | LED |  |  |  |  | 93
LED4 |  | LED5MM | LED5MM | LED |  |  |  |  | 93
LED5 |  | LED5MM | LED5MM | LED |  |  |  |  | 93
LED6 |  | LED5MM | LED5MM | LED |  |  |  |  | 93
LED7 |  | LED5MM | LED5MM | LED |  |  |  |  | 93
Q1 | 1,8432MHz | CRYSTALHC49S | HC49/S | CRYSTAL |  |  | 1667008 | unknown | 49
QG1 | 32Mhz | QG5860 | DIL14S | CRYSTAL RESONATOR |  |  | unknown | unknown | 0
R1 | 680R | R-EU_0207/10 | 0207/10 | RESISTOR, European symbol
R2 | 470R | R-EU_0207/10 | 0207/10 | RESISTOR, European symbol
R3 | 4k7 | R-EU_0204/7 | 0204/7 | RESISTOR, European symbol |  |  |  |  | 79 |  | R
R4 | 4k7 | R-EU_0204/7 | 0204/7 | RESISTOR, European symbol |  |  |  |  | 79 |  | R
R5 | 4k7 | R-EU_0204/7 | 0204/7 | RESISTOR, European symbol |  |  |  |  | 79 |  | R
R6 | 4k7 | R-EU_0204/7 | 0204/7 | RESISTOR, European symbol |  |  |  |  | 79 |  | R
R7 | 22k | R-EU_0207/10 | 0207/10 | RESISTOR, European symbol
R8 | 22k | R-EU_0207/10 | 0207/10 | RESISTOR, European symbol
R9 | 22k | R-EU_0207/10 | 0207/10 | RESISTOR, European symbol
R10 | 680R | R-EU_0207/10 | 0207/10 | RESISTOR, European symbol
R11 | 680R | R-EU_0207/10 | 0207/10 | RESISTOR, European symbol
R12 | 680R | R-EU_0207/10 | 0207/10 | RESISTOR, European symbol
R13 | 22k | R-EU_0207/10 | 0207/10 | RESISTOR, European symbol
R14 | 680R | R-EU_0207/10 | 0207/10 | RESISTOR, European symbol |  |  |  |  | 81 |  | R
R15 | 680R | R-EU_0207/10 | 0207/10 | RESISTOR, European symbol |  |  |  |  | 81 |  | R
R16 | 22K | R-EU_0207/10 | 0207/10 | RESISTOR, European symbol |  |  |  |  | 81 |  | R
R17 | 22k | R-EU_0207/10 | 0207/10 | RESISTOR, European symbol |  |  |  |  | 81 |  | R
RN1 | 22k | G08R | SIL9 | SIL RESISTOR |  |  | unknown | unknown | 6
RN2 | 22k | G08R | SIL9 | SIL RESISTOR |  |  | unknown | unknown | 6
S1 |  | 10-XX | B3F-10XX | OMRON SWITCH |  | B3F-1000 | 176432 | 36M3542 | 72
S2 |  | 10-XX | B3F-10XX | OMRON SWITCH |  | B3F-1000 | 176432 | 36M3542 | 72
S3 |  | 10-XX | B3F-10XX | OMRON SWITCH |  | B3F-1000 | 176432 | 36M3542 | 72
SJ1 |  | SJ | SJ | SMD solder JUMPER |  |  |  |  | 33
SJ2 |  | SJ | SJ | SMD solder JUMPER |  |  |  |  | 33
SJ3 |  | SJ | SJ | SMD solder JUMPER |  |  |  |  | 33
SJ4 |  | SJ | SJ | SMD solder JUMPER |  |  |  |  | 33
U$1 | MCP2221A-I/P | MCP2221A-I/P | DIL14
X1 |  | ISA-SLOT | ISA-8 | ISA SLOT
X2 |  | ISA-SLOT | ISA-8 | ISA SLOT
X3 |  | ISA-SLOT | ISA-8 | ISA SLOT
X4 |  | MINI_DIN_6 | M_DIN6

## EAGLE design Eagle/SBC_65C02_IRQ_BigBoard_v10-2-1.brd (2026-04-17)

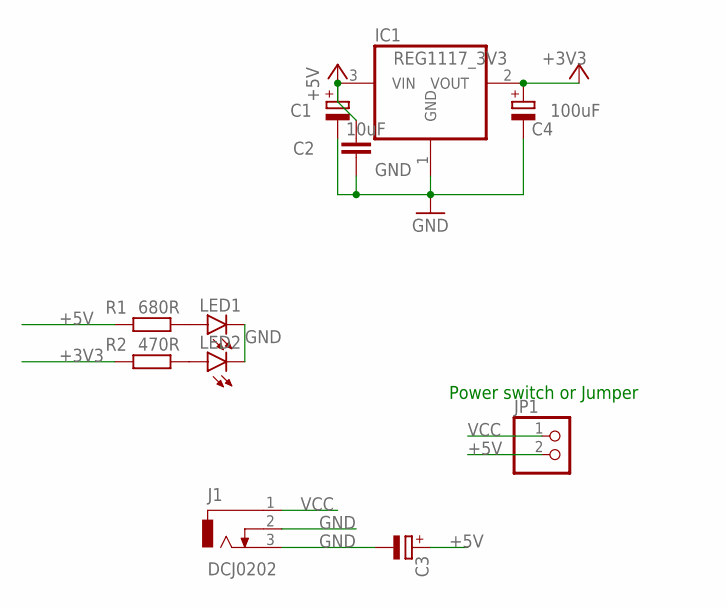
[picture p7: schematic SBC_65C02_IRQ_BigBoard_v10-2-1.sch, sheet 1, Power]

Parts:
C1: 10uF; E2,5-5
C2: C-EU050-035X075; C050-035X075
C3: CPOL-EUE2.5-5; E2,5-5
C4: 100uF; E2,5-5
IC1: REG1117_3V3; SOT223
J1: DCJ0202
JP1: PINHD-1X2; 1X02
LED1, LED2: LED5MM
R1: 680R; 0207/10
R2: 470R; 0207/10

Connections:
+3V3: C4.+, IC1.2 (VOUT), R2.2
+5V: C1.+, C2.1, C3.+, IC1.3 (VIN), JP1.2, R1.2; also elsewhere on the board
GND: C1.-, C2.2, C3.-, C4.-, IC1.1 (GND), J1.2, J1.3, LED1.K (C), LED2.K (C); also elsewhere on the board
unnamed: LED1.A, R1.1
unnamed: LED2.A, R2.1
VCC: J1.1, JP1.1

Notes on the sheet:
Power switch or Jumper

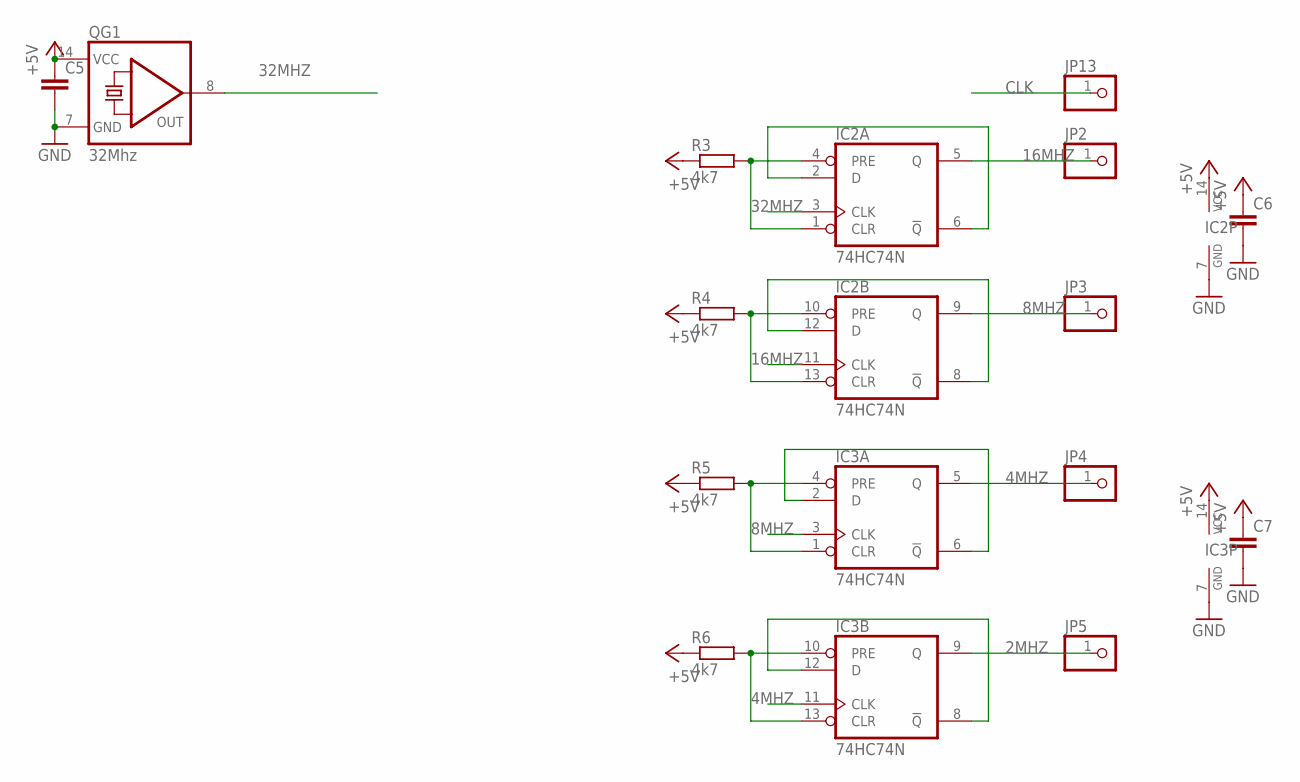
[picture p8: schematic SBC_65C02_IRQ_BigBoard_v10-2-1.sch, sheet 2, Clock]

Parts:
C5, C6, C7: C-EU050-025X075; C050-025X075
IC2, IC3: 74HC74N; DIL14
JP2, JP3, JP4, JP5, JP13: PINHD-1X1; 1X01
QG1: 32Mhz; DIL14S
R3, R4, R5, R6: 4k7; 0204/7

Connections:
2MHZ: IC3.9 (Q), JP5.1
4MHZ: IC3.5 (Q), IC3.11 (CLK), JP4.1
8MHZ: IC2.9 (Q), IC3.3 (CLK), JP3.1
16MHZ: IC2.5 (Q), IC2.11 (CLK), JP2.1
32MHZ: IC2.3 (CLK), QG1.8 (OUT); also elsewhere on the board
+5V: C5.1, C6.1, C7.1, IC2.14 (VCC), IC3.14 (VCC), QG1.14 (VCC), R3.1, R4.1, R5.1, R6.1; also elsewhere on the board
CLK: JP13.1; also elsewhere on the board
GND: C5.2, C6.2, C7.2, IC2.7 (GND), IC3.7 (GND), QG1.7 (GND); also elsewhere on the board
unnamed: IC2.2 (D), IC2.6 (!Q)
unnamed: IC2.8 (!Q), IC2.12 (D)
unnamed: IC2.1 (CLR), IC2.4 (PRE), R3.2
unnamed: IC2.10 (PRE), IC2.13 (CLR), R4.2
unnamed: IC3.2 (D), IC3.6 (!Q)
unnamed: IC3.1 (CLR), IC3.4 (PRE), R5.2
unnamed: IC3.8 (!Q), IC3.12 (D)
unnamed: IC3.10 (PRE), IC3.13 (CLR), R6.2

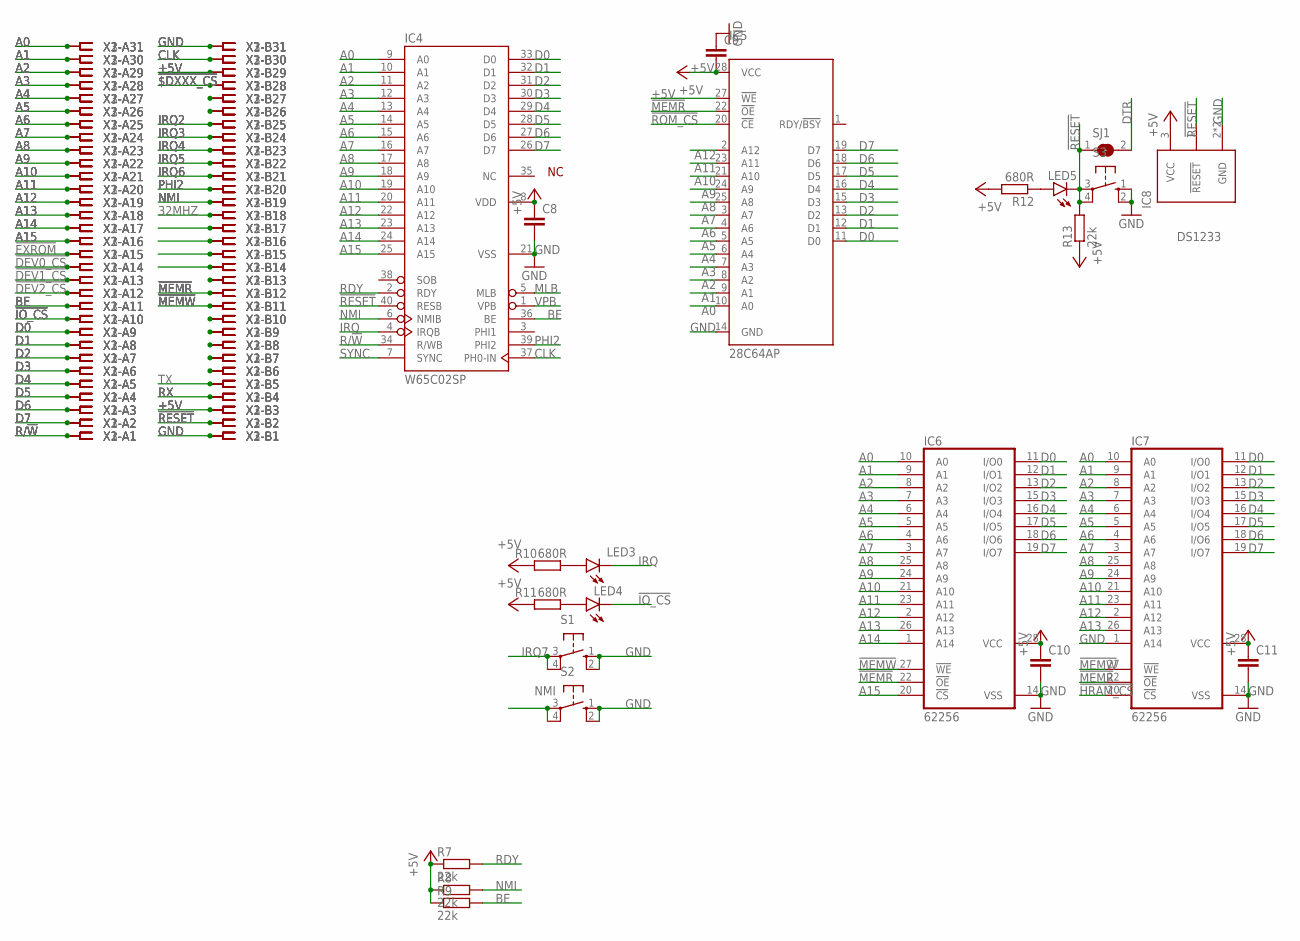
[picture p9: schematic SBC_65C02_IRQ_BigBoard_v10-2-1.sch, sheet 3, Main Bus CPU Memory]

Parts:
C8, C9, C10, C11: C-EU050-025X075; C050-025X075
IC4: W65C02SP; DIL40
IC5: 28C64AP; DIL28-6
IC6, IC7: 62256; DIL28-6
IC8: DS1233; SOT223
LED3, LED4, LED5: LED5MM
R7, R8, R9, R13: 22k; 0207/10
R10, R11, R12: 680R; 0207/10
S1, S2, S3: 10-XX; B3F-10XX
SJ1: SJ
X1, X2, X3: ISA-SLOT; ISA-8

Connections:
32MHZ: X1.B18, X2.B18, X3.B18; also elsewhere on the board
!$DXXX_CS: X1.B28, X2.B28, X3.B28; also elsewhere on the board
!DEV0_CS: X1.A14, X2.A14, X3.A14; also elsewhere on the board
!DEV1_CS: X1.A13, X2.A13, X3.A13; also elsewhere on the board
!DEV2_CS: X1.A12, X2.A12, X3.A12; also elsewhere on the board
!EXROM: X1.A15, X2.A15, X3.A15; also elsewhere on the board
!HRAM_CS: IC7.20 (!CS); also elsewhere on the board
!IO_CS: LED4.K (C), X1.A10, X2.A10, X3.A10; also elsewhere on the board
!MEMR: IC5.22 (!OE), IC6.22 (!OE), IC7.22 (!OE), X1.B12, X2.B12, X3.B12; also elsewhere on the board
!MEMW: IC6.27 (!WE), IC7.27 (!WE), X1.B11, X2.B11, X3.B11; also elsewhere on the board
!RESET: IC4.40 (RESB), IC8.1 (!RESET), LED5.K (C), R13.2, S3.3, S3.4 (P1), SJ1.1, X1.B2, X2.B2, X3.B2; also elsewhere on the board
!ROM_CS: IC5.20 (!CE); also elsewhere on the board
+5V: C8.1, C9.2, C10.1, C11.1, IC4.8 (VDD), IC5.27 (!WE), IC5.28 (VCC), IC6.28 (VCC), IC7.28 (VCC), IC8.3 (VCC), R7.1, R8.1, R9.1, R10.2, R11.2, R12.2, R13.1, X1.B3, X1.B29, X2.B3, X2.B29, X3.B3, X3.B29; also elsewhere on the board
A0: IC4.9 (A0), IC5.10 (A0), IC6.10 (A0), IC7.10 (A0), X1.A31, X2.A31, X3.A31; also elsewhere on the board
A1: IC4.10 (A1), IC5.9 (A1), IC6.9 (A1), IC7.9 (A1), X1.A30, X2.A30, X3.A30; also elsewhere on the board
A2: IC4.11 (A2), IC5.8 (A2), IC6.8 (A2), IC7.8 (A2), X1.A29, X2.A29, X3.A29; also elsewhere on the board
A3: IC4.12 (A3), IC5.7 (A3), IC6.7 (A3), IC7.7 (A3), X1.A28, X2.A28, X3.A28; also elsewhere on the board
A4: IC4.13 (A4), IC5.6 (A4), IC6.6 (A4), IC7.6 (A4), X1.A27, X2.A27, X3.A27; also elsewhere on the board
A5: IC4.14 (A5), IC5.5 (A5), IC6.5 (A5), IC7.5 (A5), X1.A26, X2.A26, X3.A26
A6: IC4.15 (A6), IC5.4 (A6), IC6.4 (A6), IC7.4 (A6), X1.A25, X2.A25, X3.A25
A7: IC4.16 (A7), IC5.3 (A7), IC6.3 (A7), IC7.3 (A7), X1.A24, X2.A24, X3.A24; also elsewhere on the board
A8: IC4.17 (A8), IC5.25 (A8), IC6.25 (A8), IC7.25 (A8), X1.A23, X2.A23, X3.A23; also elsewhere on the board
A9: IC4.18 (A9), IC5.24 (A9), IC6.24 (A9), IC7.24 (A9), X1.A22, X2.A22, X3.A22; also elsewhere on the board
A10: IC4.19 (A10), IC5.21 (A10), IC6.21 (A10), IC7.21 (A10), X1.A21, X2.A21, X3.A21; also elsewhere on the board
A11: IC4.20 (A11), IC5.23 (A11), IC6.23 (A11), IC7.23 (A11), X1.A20, X2.A20, X3.A20; also elsewhere on the board
A12: IC4.22 (A12), IC5.2 (A12), IC6.2 (A12), IC7.2 (A12), X1.A19, X2.A19, X3.A19; also elsewhere on the board
A13: IC4.23 (A13), IC6.26 (A13), IC7.26 (A13), X1.A18, X2.A18, X3.A18; also elsewhere on the board
A14: IC4.24 (A14), IC6.1 (A14), X1.A17, X2.A17, X3.A17; also elsewhere on the board
A15: IC4.25 (A15), IC6.20 (!CS), X1.A16, X2.A16, X3.A16; also elsewhere on the board
BE: IC4.36 (BE), R9.2, X1.A11, X2.A11, X3.A11
CLK: IC4.37 (PH0-IN), X1.B30, X2.B30, X3.B30; also elsewhere on the board
CS_1: X1.B27, X2.B27, X3.B27
CS_2: X1.B26, X2.B26, X3.B26
D0: IC4.33 (D0), IC5.11 (D0), IC6.11 (I/O0), IC7.11 (I/O0), X1.A9, X2.A9, X3.A9; also elsewhere on the board
D1: IC4.32 (D1), IC5.12 (D1), IC6.12 (I/O1), IC7.12 (I/O1), X1.A8, X2.A8, X3.A8; also elsewhere on the board
D2: IC4.31 (D2), IC5.13 (D2), IC6.13 (I/O2), IC7.13 (I/O2), X1.A7, X2.A7, X3.A7; also elsewhere on the board
D3: IC4.30 (D3), IC5.15 (D3), IC6.15 (I/O3), IC7.15 (I/O3), X1.A6, X2.A6, X3.A6; also elsewhere on the board
D4: IC4.29 (D4), IC5.16 (D4), IC6.16 (I/O4), IC7.16 (I/O4), X1.A5, X2.A5, X3.A5; also elsewhere on the board
D5: IC4.28 (D5), IC5.17 (D5), IC6.17 (I/O5), IC7.17 (I/O5), X1.A4, X2.A4, X3.A4; also elsewhere on the board
D6: IC4.27 (D6), IC5.18 (D6), IC6.18 (I/O6), IC7.18 (I/O6), X1.A3, X2.A3, X3.A3; also elsewhere on the board
D7: IC4.26 (D7), IC5.19 (D7), IC6.19 (I/O7), IC7.19 (I/O7), X1.A2, X2.A2, X3.A2; also elsewhere on the board
DTR: SJ1.2; also elsewhere on the board
GND: C8.2, C9.1, C10.2, C11.2, IC4.21 (VSS), IC5.14 (GND), IC6.14 (VSS), IC7.1 (A14), IC7.14 (VSS), IC8.2 (GND), IC8.4 (GND), S1.1 (S), S1.2 (S1), S2.1 (S), S2.2 (S1), S3.1 (S), S3.2 (S1), X1.B1, X1.B31, X2.B1, X2.B31, X3.B1, X3.B31; also elsewhere on the board
IRQ: IC4.4 (IRQB), LED3.K (C); also elsewhere on the board
IRQ2: X1.B25, X2.B25, X3.B25; also elsewhere on the board
IRQ3: X1.B24, X2.B24, X3.B24; also elsewhere on the board
IRQ4: X1.B23, X2.B23, X3.B23; also elsewhere on the board
IRQ5: X1.B22, X2.B22, X3.B22; also elsewhere on the board
IRQ6: X1.B21, X2.B21, X3.B21; also elsewhere on the board
IRQ7: S1.3, S1.4 (P1); also elsewhere on the board
MLB: IC4.5 (MLB)
unnamed: LED3.A, R10.1
unnamed: LED5.A, R12.1
unnamed: X1.B6, X2.B6, X3.B6
unnamed: X1.B7, X2.B7, X3.B7
unnamed: X1.B8, X2.B8, X3.B8
unnamed: LED4.A, R11.1
unnamed: X1.B9, X2.B9, X3.B9
unnamed: X1.B10, X2.B10, X3.B10
unnamed: X1.B13, X2.B13, X3.B13
unnamed: X1.B14, X2.B14, X3.B14
NMI: IC4.6 (NMIB), R8.2, S2.3, S2.4 (P1), X1.B19, X2.B19, X3.B19; also elsewhere on the board
PHI2: IC4.39 (PHI2), X1.B20, X2.B20, X3.B20; also elsewhere on the board
R/!W: IC4.34 (R/WB), X1.A1, X2.A1, X3.A1; also elsewhere on the board
RDY: IC4.2 (RDY), R7.2
RX: X1.B4, X2.B4, X3.B4; also elsewhere on the board
SPI_MOSI: X1.B17, X2.B17, X3.B17
SPI_NSEL2: X1.B15, X2.B15, X3.B15
SPI_SCLK: X1.B16, X2.B16, X3.B16
SYNC: IC4.7 (SYNC)
TX: X1.B5, X2.B5, X3.B5; also elsewhere on the board
VPB: IC4.1 (VPB)

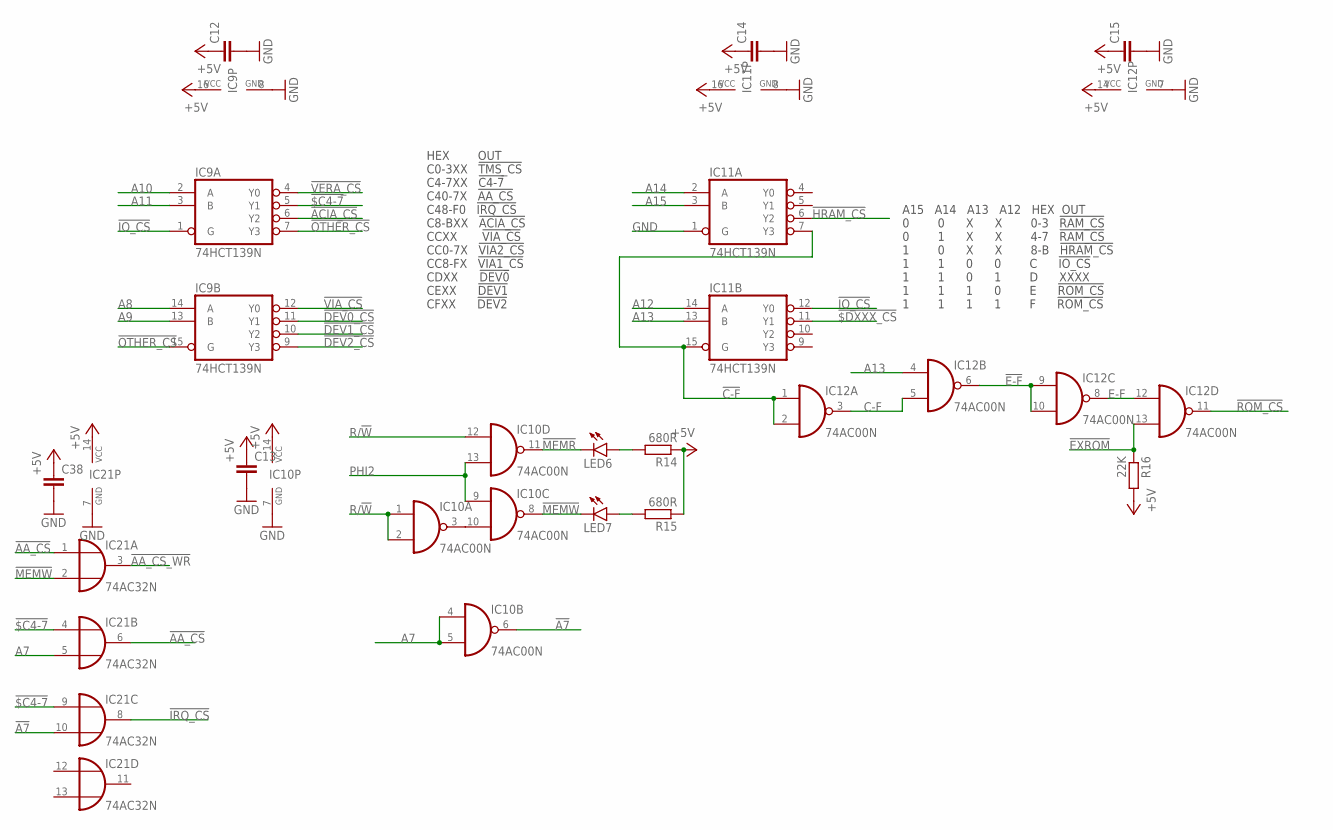
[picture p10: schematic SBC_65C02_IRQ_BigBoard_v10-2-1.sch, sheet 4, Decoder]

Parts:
C12, C13, C14, C15, C38: C-EU050-025X075; C050-025X075
IC9, IC11: 74HCT139N; DIL16
IC10, IC12: 74AC00N; DIL14
IC21: 74AC32N; DIL14
LED6, LED7: LED5MM
R14, R15: 680R; 0207/10
R16: 22K; 0207/10

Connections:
!$C4-7: IC9.5 (Y1), IC21.4 (I0), IC21.9 (I0)
!$DXXX_CS: IC11.11 (Y1); also elsewhere on the board
!A7: IC10.6 (O), IC21.10 (I1); also elsewhere on the board
!AA_CS: IC21.1 (I0), IC21.6 (O)
!AA_CS_WR: IC21.3 (O)
!ACIA_CS: IC9.6 (Y2); also elsewhere on the board
!C-F: IC11.7 (Y3), IC11.15 (G), IC12.1 (I0), IC12.2 (I1)
!DEV0_CS: IC9.11 (Y1); also elsewhere on the board
!DEV1_CS: IC9.10 (Y2); also elsewhere on the board
!DEV2_CS: IC9.9 (Y3); also elsewhere on the board
!E-F: IC12.6 (O), IC12.9 (I0), IC12.10 (I1)
!EXROM: IC12.13 (I1), R16.1; also elsewhere on the board
!HRAM_CS: IC11.6 (Y2); also elsewhere on the board
!IO_CS: IC9.1 (G), IC11.12 (Y0); also elsewhere on the board
!IRQ_CS: IC21.8 (O); also elsewhere on the board
!MEMR: IC10.11 (O), LED6.K (C); also elsewhere on the board
!MEMW: IC10.8 (O), IC21.2 (I1), LED7.K (C); also elsewhere on the board
!OTHER_CS: IC9.7 (Y3), IC9.15 (G)
!ROM_CS: IC12.11 (O); also elsewhere on the board
!VERA_CS: IC9.4 (Y0); also elsewhere on the board
!VIA_CS: IC9.12 (Y0); also elsewhere on the board
+5V: C12.1, C13.1, C14.1, C15.1, C38.1, IC9.16 (VCC), IC10.14 (VCC), IC11.16 (VCC), IC12.14 (VCC), IC21.14 (VCC), R14.1, R15.1, R16.2; also elsewhere on the board
A7: IC10.4 (I0), IC10.5 (I1), IC21.5 (I1); also elsewhere on the board
A8: IC9.14 (A); also elsewhere on the board
A9: IC9.13 (B); also elsewhere on the board
A10: IC9.2 (A); also elsewhere on the board
A11: IC9.3 (B); also elsewhere on the board
A12: IC11.14 (A); also elsewhere on the board
A13: IC11.13 (B), IC12.4 (I0); also elsewhere on the board
A14: IC11.2 (A); also elsewhere on the board
A15: IC11.3 (B); also elsewhere on the board
C-F: IC12.3 (O), IC12.5 (I1)
E-F: IC12.8 (O), IC12.12 (I0)
GND: C12.2, C13.2, C14.2, C15.2, C38.2, IC9.8 (GND), IC10.7 (GND), IC11.1 (G), IC11.8 (GND), IC12.7 (GND), IC21.7 (GND); also elsewhere on the board
unnamed: LED6.A, R14.2
unnamed: LED7.A, R15.2
unnamed: IC10.3 (O), IC10.10 (I1)
PHI2: IC10.9 (I0), IC10.13 (I1); also elsewhere on the board
R/!W: IC10.1 (I0), IC10.2 (I1), IC10.12 (I0); also elsewhere on the board

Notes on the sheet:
HEX OUT C0-3XX !TMS_CS C4-7XX !C4-7 C40-7X !AA_CS C48-F0 !IRQ_CS C8-BXX !ACIA_CS CCXX !VIA_CS CC0-7X !VIA2_CS CC8-FX !VIA1_CS CDXX !DEV0 CEXX !DEV1 CFXX !DEV2
A15 A14 A13 A12 HEX OUT 0 0 X X 0-3 !RAM_CS 0 1 X X 4-7 !RAM_CS 1 0 X X 8-B !HRAM_CS 1 1 0 0 C !IO_CS 1 1 0 1 D XXXX 1 1 1 0 E !ROM_CS 1 1 1 1 F !ROM_CS

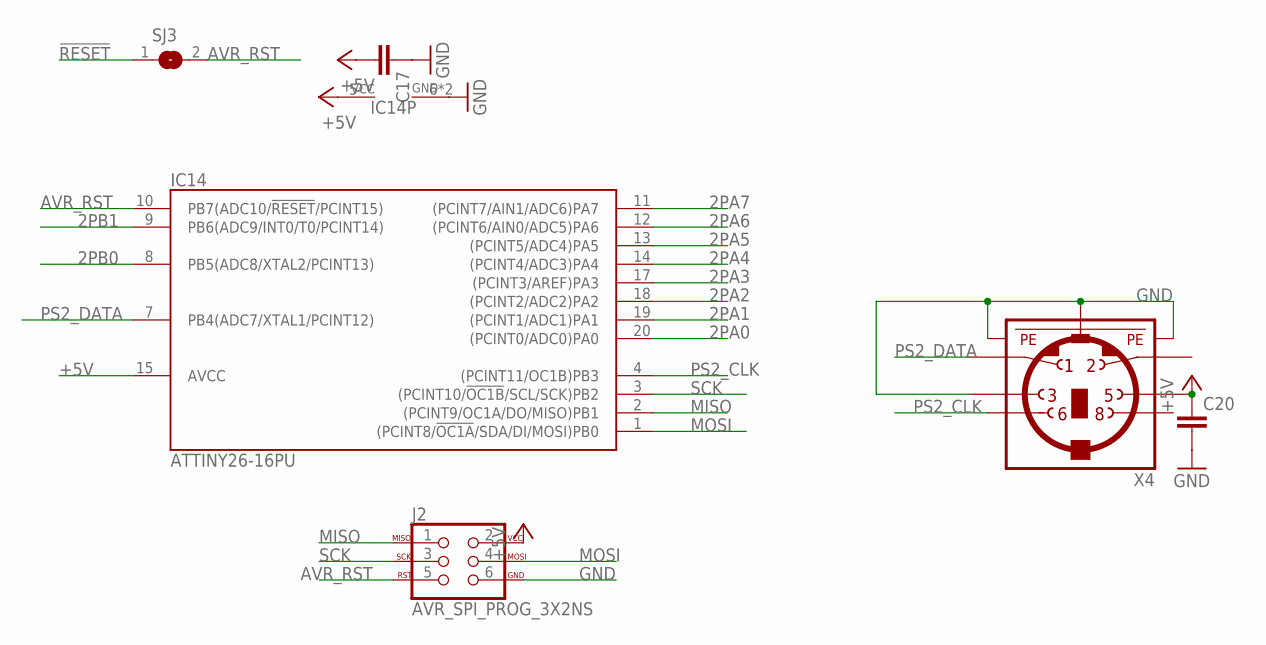
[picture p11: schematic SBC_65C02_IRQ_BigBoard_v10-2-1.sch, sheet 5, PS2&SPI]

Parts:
C17, C20: C-EU050-025X075; C050-025X075
IC14: ATTINY26-16PU; DIL20
J2: AVR_SPI_PROG_3X2NS; 2X3-NS
SJ3: SJ
X4: MINI_DIN_6; M_DIN6

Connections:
2PA0: IC14.20 ((PCINT0/ADC0)PA0); also elsewhere on the board
2PA1: IC14.19 ((PCINT1/ADC1)PA1); also elsewhere on the board
2PA2: IC14.18 ((PCINT2/ADC2)PA2); also elsewhere on the board
2PA3: IC14.17 ((PCINT3/AREF)PA3); also elsewhere on the board
2PA4: IC14.14 ((PCINT4/ADC3)PA4); also elsewhere on the board
2PA5: IC14.13 ((PCINT5/ADC4)PA5); also elsewhere on the board
2PA6: IC14.12 ((PCINT6/AIN0/ADC5)PA6); also elsewhere on the board
2PA7: IC14.11 ((PCINT7/AIN1/ADC6)PA7); also elsewhere on the board
2PB0: IC14.8 (PB5(ADC8/XTAL2/PCINT13)); also elsewhere on the board
2PB1: IC14.9 (PB6(ADC9/INT0/T0/PCINT14)); also elsewhere on the board
!RESET: SJ3.1; also elsewhere on the board
+5V: C17.2, C20.1, IC14.5 (VCC), IC14.15 (AVCC), J2.2, X4.5; also elsewhere on the board
AVR_RST: IC14.10 (PB7(ADC10/!RESET!/PCINT15)), J2.5, SJ3.2
GND: C17.1, C20.2, IC14.6 (GND), IC14.16 (GND), J2.6, X4.3, X4.SH1 (PE1), X4.SH2 (PE2), X4.SH3 (PE3); also elsewhere on the board
MISO: IC14.2 ((PCINT9/OC1A/DO/MISO)PB1), J2.1
MOSI: IC14.1 ((PCINT8/!OC1A!/SDA/DI/MOSI)PB0), J2.4
PS2_CLK: IC14.4 ((PCINT11/OC1B)PB3), X4.6
PS2_DATA: IC14.7 (PB4(ADC7/XTAL1/PCINT12)), X4.1
SCK: IC14.3 ((PCINT10/!OC1B!/SCL/SCK)PB2), J2.3

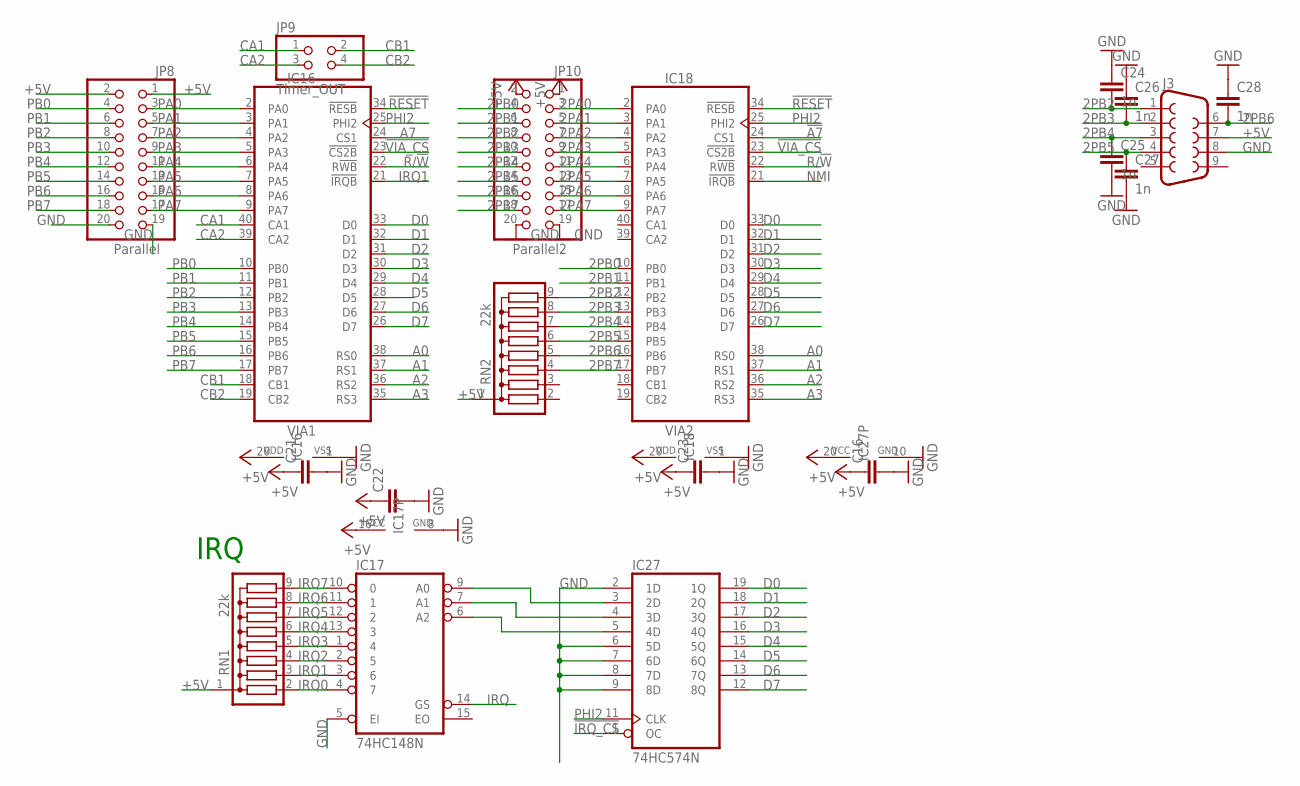
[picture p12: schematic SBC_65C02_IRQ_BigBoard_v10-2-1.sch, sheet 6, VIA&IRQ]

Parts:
C16, C21, C22, C23: C-EU050-025X075; C050-025X075
C24, C25, C26, C27, C28: 1n; C050-025X075
IC16: VIA1; DIL40
IC17: 74HC148N; DIL16
IC18: VIA2; DIL40
IC27: 74HC574N; DIL20
J3: DB9MALE; DB9_MALE
JP8: Parallel; 2X10
JP9: Timer_OUT; 2X02
JP10: Parallel2; 2X10
RN1, RN2: 22k; SIL9

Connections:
2PA0: IC18.2 (PA0), JP10.3; also elsewhere on the board
2PA1: IC18.3 (PA1), JP10.5; also elsewhere on the board
2PA2: IC18.4 (PA2), JP10.7; also elsewhere on the board
2PA3: IC18.5 (PA3), JP10.9; also elsewhere on the board
2PA4: IC18.6 (PA4), JP10.11; also elsewhere on the board
2PA5: IC18.7 (PA5), JP10.13; also elsewhere on the board
2PA6: IC18.8 (PA6), JP10.15; also elsewhere on the board
2PA7: IC18.9 (PA7), JP10.17; also elsewhere on the board
2PB0: IC18.10 (PB0), JP10.4; also elsewhere on the board
2PB1: IC18.11 (PB1), JP10.6; also elsewhere on the board
2PB2: C24.2, IC18.12 (PB2), J3.1, JP10.8, RN2.9
2PB3: C26.2, IC18.13 (PB3), J3.2, JP10.10, RN2.8
2PB4: C25.1, IC18.14 (PB4), J3.3, JP10.12, RN2.7
2PB5: C27.1, IC18.15 (PB5), J3.4, JP10.14, RN2.6
2PB6: C28.2, IC18.16 (PB6), J3.6, JP10.16, RN2.5
2PB7: IC18.17 (PB7), JP10.18, RN2.4
!A7: IC18.24 (CS1); also elsewhere on the board
!IRQ_CS: IC27.1 (OC); also elsewhere on the board
!RESET: IC16.34 (!RESB), IC18.34 (!RESB); also elsewhere on the board
!VIA_CS: IC16.23 (!CS2B), IC18.23 (!CS2B); also elsewhere on the board
+5V: C16.1, C21.1, C22.1, C23.1, IC16.20 (VDD), IC17.16 (VCC), IC18.20 (VDD), IC27.20 (VCC), J3.7, JP8.1, JP8.2, JP10.1, JP10.2, RN1.1, RN2.1; also elsewhere on the board
A0: IC16.38 (RS0), IC18.38 (RS0); also elsewhere on the board
A1: IC16.37 (RS1), IC18.37 (RS1); also elsewhere on the board
A2: IC16.36 (RS2), IC18.36 (RS2); also elsewhere on the board
A3: IC16.35 (RS3), IC18.35 (RS3); also elsewhere on the board
A7: IC16.24 (CS1); also elsewhere on the board
CA1: IC16.40 (CA1), JP9.1
CA2: IC16.39 (CA2), JP9.3
CB1: IC16.18 (CB1), JP9.2
CB2: IC16.19 (CB2), JP9.4
D0: IC16.33 (D0), IC18.33 (D0), IC27.19 (1Q); also elsewhere on the board
D1: IC16.32 (D1), IC18.32 (D1), IC27.18 (2Q); also elsewhere on the board
D2: IC16.31 (D2), IC18.31 (D2), IC27.17 (3Q); also elsewhere on the board
D3: IC16.30 (D3), IC18.30 (D3), IC27.16 (4Q); also elsewhere on the board
D4: IC16.29 (D4), IC18.29 (D4), IC27.15 (5Q); also elsewhere on the board
D5: IC16.28 (D5), IC18.28 (D5), IC27.14 (6Q); also elsewhere on the board
D6: IC16.27 (D6), IC18.27 (D6), IC27.13 (7Q); also elsewhere on the board
D7: IC16.26 (D7), IC18.26 (D7), IC27.12 (8Q); also elsewhere on the board
GND: C16.2, C21.2, C22.2, C23.2, C24.1, C25.2, C26.1, C27.2, C28.1, IC16.1 (VSS), IC17.5 (EI), IC17.8 (GND), IC18.1 (VSS), IC27.2 (1D), IC27.6 (5D), IC27.7 (6D), IC27.8 (7D), IC27.9 (8D), IC27.10 (GND), J3.8, JP8.19, JP8.20, JP10.19, JP10.20; also elsewhere on the board
IRQ: IC17.14 (GS); also elsewhere on the board
IRQ0: IC17.4 (7), RN1.2; also elsewhere on the board
IRQ1: IC16.21 (!IRQB), IC17.3 (6), RN1.3
IRQ2: IC17.2 (5), RN1.4; also elsewhere on the board
IRQ3: IC17.1 (4), RN1.5; also elsewhere on the board
IRQ4: IC17.13 (3), RN1.6; also elsewhere on the board
IRQ5: IC17.12 (2), RN1.7; also elsewhere on the board
IRQ6: IC17.11 (1), RN1.8; also elsewhere on the board
IRQ7: IC17.10 (0), RN1.9; also elsewhere on the board
unnamed: IC17.9 (A0), IC27.3 (2D)
unnamed: IC17.7 (A1), IC27.4 (3D)
unnamed: IC17.6 (A2), IC27.5 (4D)
NMI: IC18.21 (!IRQB); also elsewhere on the board
PA0: IC16.2 (PA0), JP8.3
PA1: IC16.3 (PA1), JP8.5
PA2: IC16.4 (PA2), JP8.7
PA3: IC16.5 (PA3), JP8.9
PA4: IC16.6 (PA4), JP8.11
PA5: IC16.7 (PA5), JP8.13
PA6: IC16.8 (PA6), JP8.15
PA7: IC16.9 (PA7), JP8.17
PB0: IC16.10 (PB0), JP8.4
PB1: IC16.11 (PB1), JP8.6
PB2: IC16.12 (PB2), JP8.8
PB3: IC16.13 (PB3), JP8.10
PB4: IC16.14 (PB4), JP8.12
PB5: IC16.15 (PB5), JP8.14
PB6: IC16.16 (PB6), JP8.16
PB7: IC16.17 (PB7), JP8.18
PHI2: IC16.25 (PHI2), IC18.25 (PHI2), IC27.11 (CLK); also elsewhere on the board
R/!W: IC16.22 (R!WB), IC18.22 (R!WB); also elsewhere on the board

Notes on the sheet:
IRQ

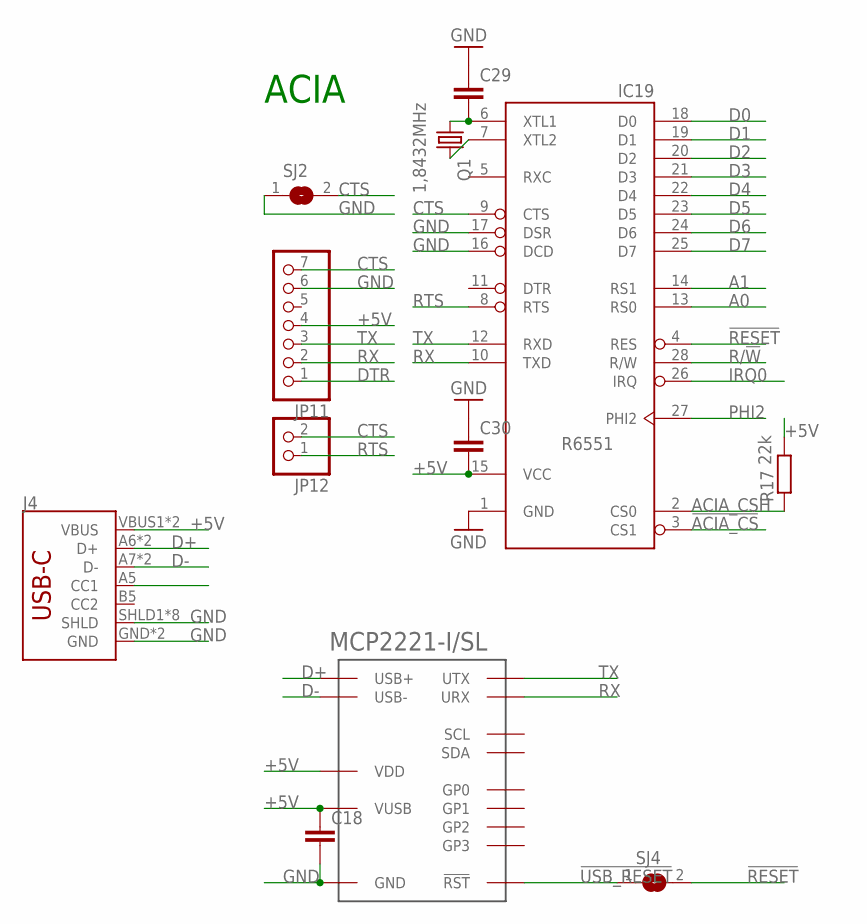
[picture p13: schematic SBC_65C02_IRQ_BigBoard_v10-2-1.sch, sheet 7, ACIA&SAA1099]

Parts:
C18, C29, C30: C-EU050-025X075; C050-025X075
IC19: R6551; DIP-28
J4: USB_C2-LAYER; USB-C-16P
JP11: PINHD-1X7; 1X07
JP12: PINHD-1X2; 1X02
Q1: 1,8432MHz; HC49/S
R17: 22k; 0207/10
SJ2, SJ4: SJ
U$1: MCP2221A-I/P; DIL14

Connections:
!ACIA_CS: IC19.3 (CS1); also elsewhere on the board
!RESET: IC19.4 (RES), SJ4.2; also elsewhere on the board
!USB_RESET: SJ4.1, U$1.4 (!RST)
+5V: C18.1, C30.2, IC19.15 (VCC), J4.VBUS1 (VBUS), J4.VBUS2 (VBUS), JP11.4, R17.2, U$1.1 (VDD), U$1.11 (VUSB); also elsewhere on the board
A0: IC19.13 (RS0); also elsewhere on the board
A1: IC19.14 (RS1); also elsewhere on the board
ACIA_CSH: IC19.2 (CS0), R17.1
CTS: IC19.9 (CTS), JP11.7, JP12.2, SJ2.2
D0: IC19.18 (D0); also elsewhere on the board
D1: IC19.19 (D1); also elsewhere on the board
D2: IC19.20 (D2); also elsewhere on the board
D3: IC19.21 (D3); also elsewhere on the board
D4: IC19.22 (D4); also elsewhere on the board
D5: IC19.23 (D5); also elsewhere on the board
D6: IC19.24 (D6); also elsewhere on the board
D7: IC19.25 (D7); also elsewhere on the board
D+: J4.A6 (D+), J4.B6 (D+), U$1.13 (USB+)
D-: J4.A7 (D-), J4.B7 (D-), U$1.12 (USB-)
DTR: JP11.1; also elsewhere on the board
GND: C18.2, C29.1, C30.1, IC19.1 (GND), IC19.16 (DCD), IC19.17 (DSR), J4.GND, J4.GND2 (GND), J4.SHLD1 (SHLD), J4.SHLD2 (SHLD), J4.SHLD3 (SHLD), J4.SHLD4 (SHLD), J4.SHLD5 (SHLD), J4.SHLD6 (SHLD), J4.SHLD7 (SHLD), J4.SHLD8 (SHLD), JP11.6, SJ2.1, U$1.14 (GND); also elsewhere on the board
IRQ0: IC19.26 (IRQ); also elsewhere on the board
unnamed: C29.2, IC19.6 (XTL1), Q1.1
unnamed: IC19.7 (XTL2), Q1.2
PHI2: IC19.27 (PHI2); also elsewhere on the board
R/!W: IC19.28 (R/W); also elsewhere on the board
RTS: IC19.8 (RTS), JP12.1
RX: IC19.10 (TXD), JP11.2, U$1.5 (URX); also elsewhere on the board
TX: IC19.12 (RXD), JP11.3, U$1.6 (UTX); also elsewhere on the board

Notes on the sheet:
ACIA

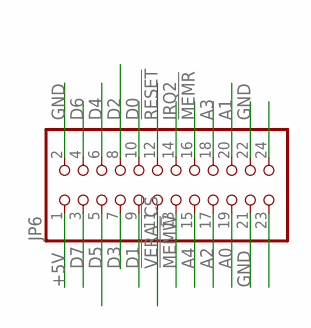
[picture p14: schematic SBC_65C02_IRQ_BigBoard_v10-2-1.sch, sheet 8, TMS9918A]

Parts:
JP6: PINHD-2X12; 2X12

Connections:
!MEMR: JP6.16; also elsewhere on the board
!MEMW: JP6.13; also elsewhere on the board
!RESET: JP6.12; also elsewhere on the board
!VERA_CS: JP6.11; also elsewhere on the board
+5V: JP6.1; also elsewhere on the board
A0: JP6.19; also elsewhere on the board
A1: JP6.20; also elsewhere on the board
A2: JP6.17; also elsewhere on the board
A3: JP6.18; also elsewhere on the board
A4: JP6.15; also elsewhere on the board
D0: JP6.10; also elsewhere on the board
D1: JP6.9; also elsewhere on the board
D2: JP6.8; also elsewhere on the board
D3: JP6.7; also elsewhere on the board
D4: JP6.6; also elsewhere on the board
D5: JP6.5; also elsewhere on the board
D6: JP6.4; also elsewhere on the board
D7: JP6.3; also elsewhere on the board
GND: JP6.2, JP6.21, JP6.22; also elsewhere on the board
IRQ2: JP6.14; also elsewhere on the board

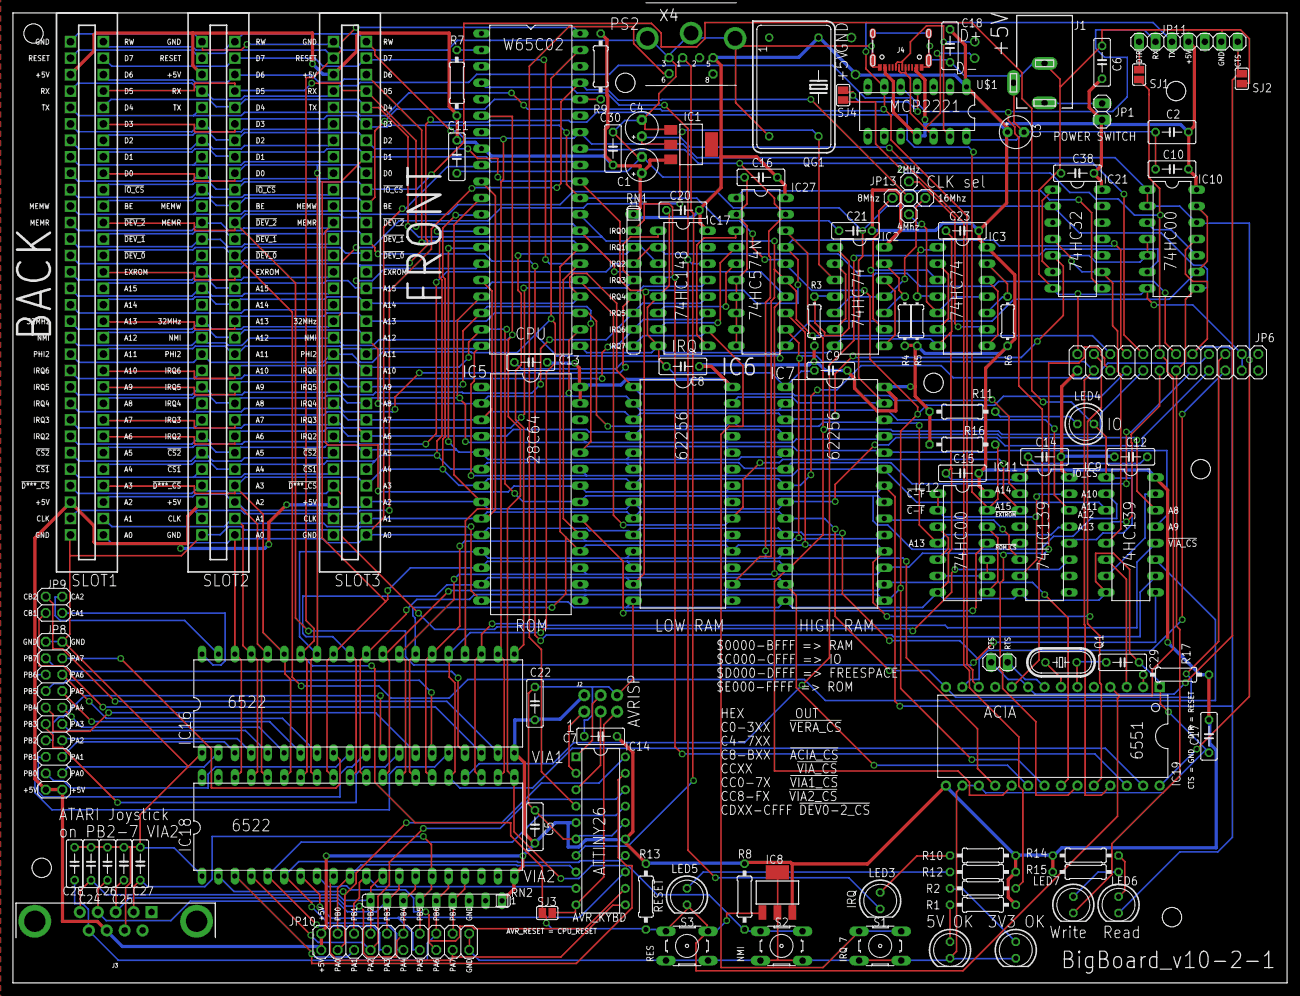
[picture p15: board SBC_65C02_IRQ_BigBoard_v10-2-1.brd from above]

Board: 2 copper layers, 196.8 x 149.9 mm, 105 parts (0 on the bottom side), 155 nets.

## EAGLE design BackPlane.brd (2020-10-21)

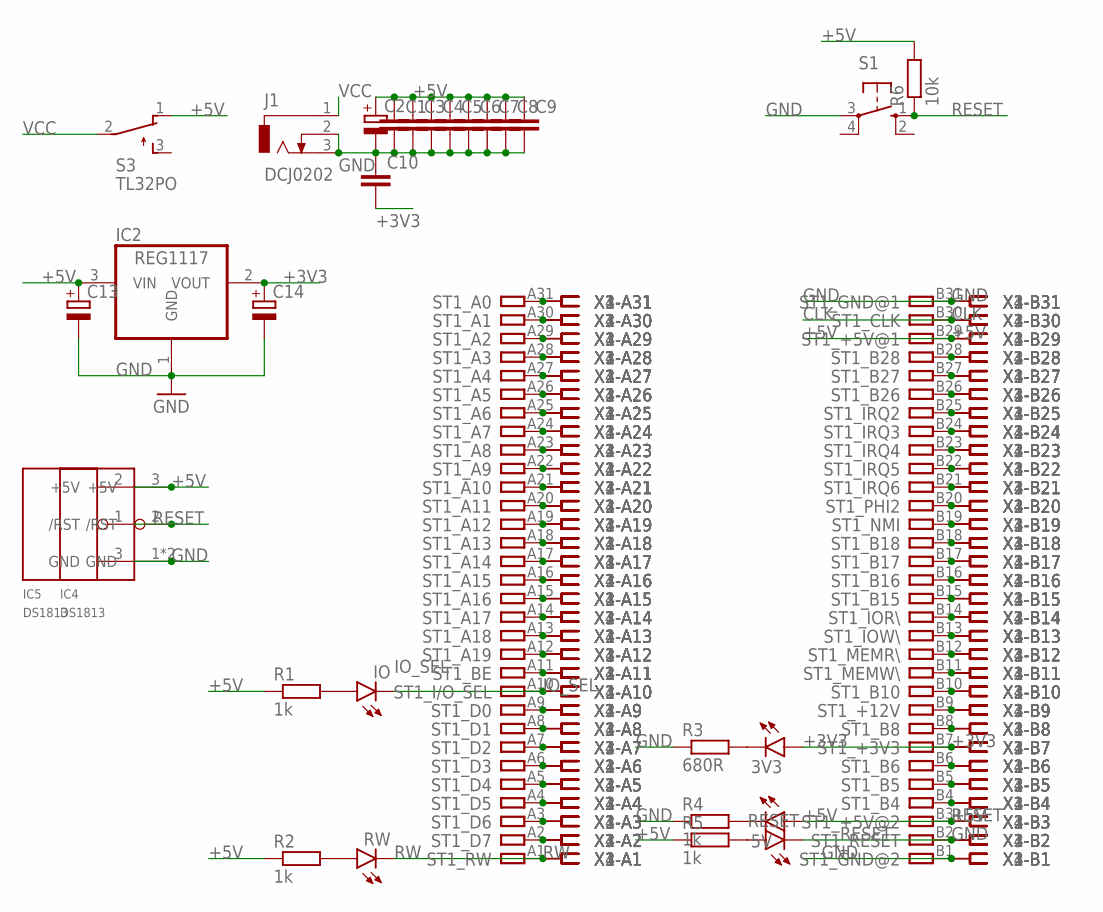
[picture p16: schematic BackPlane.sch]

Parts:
3V3, 5V: LED3MM
C1, C3, C4, C5, C6, C7, C8, C9: C-EU050-024X044; C050-024X044
C2: CPOL-EUE3.5-8; E3,5-8
C10: C-EU025-024X044; C025-024X044
C13, C14: CPOL-EUE2.5-5; E2,5-5
IC2: REG1117; SOT223
IC4: DS1813; SOT223
IC5: DS1813; TO-92
IO: LED3MM
J1: DCJ0202
R1, R2, R4, R5: 1k; 0207/7
R3: 680R; 0207/7
R6: 10k; 0207/7
RESET: LED3MM
RW: LED3MM
S1: 10-XX; B3F-10XX
S3: TL32PO; TL3XPO
ST1: IBM8BIT_ISASHORT; APP_2X32_SHORT
X1, X2, X3, X4: ISA-SLOT; ISA-8

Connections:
+3V3: 3V3.A, C10.2, C14.+, IC2.2 (VOUT), ST1.B7, X1.B7, X2.B7, X3.B7, X4.B7
+5V: 5V.A, C1.1, C2.+, C3.1, C4.1, C5.1, C6.1, C7.1, C8.1, C9.1, C13.+, IC2.3 (VIN), IC4.3 (+5V), IC5.2 (+5V), R1.1, R2.1, R5.1, R6.2, S3.1 (O), ST1.B3, ST1.B29, X1.B3, X1.B29, X2.B3, X2.B29, X3.B3, X3.B29, X4.B3, X4.B29
CLK: ST1.B30, X1.B30, X2.B30, X3.B30, X4.B30
GND: C1.2, C2.-, C3.2, C4.2, C5.2, C6.2, C7.2, C8.2, C9.2, C10.1, C13.-, C14.-, IC2.1 (GND), IC4.1 (GND), IC4.4 (GND), IC5.3 (GND), J1.2, J1.3, R3.1, R4.1, S1.3, ST1.B1, ST1.B31, X1.B1, X1.B31, X2.B1, X2.B31, X3.B1, X3.B31, X4.B1, X4.B31
IO_SEL: IO.K (C), ST1.A10, X1.A10, X2.A10, X3.A10, X4.A10
unnamed: IO.A, R1.2
unnamed: ST1.A2, X1.A2, X2.A2, X3.A2, X4.A2
unnamed: ST1.A3, X1.A3, X2.A3, X3.A3, X4.A3
unnamed: ST1.A4, X1.A4, X2.A4, X3.A4, X4.A4
unnamed: ST1.A5, X1.A5, X2.A5, X3.A5, X4.A5
unnamed: ST1.A6, X1.A6, X2.A6, X3.A6, X4.A6
unnamed: ST1.A7, X1.A7, X2.A7, X3.A7, X4.A7
unnamed: ST1.A8, X1.A8, X2.A8, X3.A8, X4.A8
unnamed: ST1.A9, X1.A9, X2.A9, X3.A9, X4.A9
unnamed: R2.2, RW.A
unnamed: ST1.A11, X1.A11, X2.A11, X3.A11, X4.A11
unnamed: ST1.A12, X1.A12, X2.A12, X3.A12, X4.A12
unnamed: ST1.A13, X1.A13, X2.A13, X3.A13, X4.A13
unnamed: ST1.A14, X1.A14, X2.A14, X3.A14, X4.A14
unnamed: ST1.A15, X1.A15, X2.A15, X3.A15, X4.A15
unnamed: ST1.A16, X1.A16, X2.A16, X3.A16, X4.A16
unnamed: ST1.A17, X1.A17, X2.A17, X3.A17, X4.A17
unnamed: ST1.A18, X1.A18, X2.A18, X3.A18, X4.A18
unnamed: ST1.A19, X1.A19, X2.A19, X3.A19, X4.A19
unnamed: ST1.A20, X1.A20, X2.A20, X3.A20, X4.A20
unnamed: ST1.A21, X1.A21, X2.A21, X3.A21, X4.A21
unnamed: ST1.A22, X1.A22, X2.A22, X3.A22, X4.A22
unnamed: ST1.A23, X1.A23, X2.A23, X3.A23, X4.A23
unnamed: ST1.A24, X1.A24, X2.A24, X3.A24, X4.A24
unnamed: ST1.A25, X1.A25, X2.A25, X3.A25, X4.A25
unnamed: ST1.A26, X1.A26, X2.A26, X3.A26, X4.A26
unnamed: ST1.A27, X1.A27, X2.A27, X3.A27, X4.A27
unnamed: ST1.A28, X1.A28, X2.A28, X3.A28, X4.A28
unnamed: ST1.A29, X1.A29, X2.A29, X3.A29, X4.A29
unnamed: ST1.A30, X1.A30, X2.A30, X3.A30, X4.A30
unnamed: ST1.A31, X1.A31, X2.A31, X3.A31, X4.A31
unnamed: ST1.B4, X1.B4, X2.B4, X3.B4, X4.B4
unnamed: ST1.B5, X1.B5, X2.B5, X3.B5, X4.B5
unnamed: ST1.B6, X1.B6, X2.B6, X3.B6, X4.B6
unnamed: ST1.B8, X1.B8, X2.B8, X3.B8, X4.B8
unnamed: ST1.B9, X1.B9, X2.B9, X3.B9, X4.B9
unnamed: ST1.B10, X1.B10, X2.B10, X3.B10, X4.B10
unnamed: ST1.B11, X1.B11, X2.B11, X3.B11, X4.B11
unnamed: ST1.B12, X1.B12, X2.B12, X3.B12, X4.B12
unnamed: ST1.B13, X1.B13, X2.B13, X3.B13, X4.B13
unnamed: ST1.B14, X1.B14, X2.B14, X3.B14, X4.B14
unnamed: ST1.B15, X1.B15, X2.B15, X3.B15, X4.B15
unnamed: ST1.B16, X1.B16, X2.B16, X3.B16, X4.B16
unnamed: ST1.B17, X1.B17, X2.B17, X3.B17, X4.B17
unnamed: ST1.B18, X1.B18, X2.B18, X3.B18, X4.B18
unnamed: ST1.B19, X1.B19, X2.B19, X3.B19, X4.B19
unnamed: ST1.B20, X1.B20, X2.B20, X3.B20, X4.B20
unnamed: ST1.B21, X1.B21, X2.B21, X3.B21, X4.B21
unnamed: ST1.B22, X1.B22, X2.B22, X3.B22, X4.B22
unnamed: ST1.B23, X1.B23, X2.B23, X3.B23, X4.B23
unnamed: ST1.B24, X1.B24, X2.B24, X3.B24, X4.B24
unnamed: ST1.B25, X1.B25, X2.B25, X3.B25, X4.B25
unnamed: ST1.B26, X1.B26, X2.B26, X3.B26, X4.B26
unnamed: ST1.B27, X1.B27, X2.B27, X3.B27, X4.B27
unnamed: ST1.B28, X1.B28, X2.B28, X3.B28, X4.B28
unnamed: 3V3.K (C), R3.2
unnamed: 5V.K (C), R4.2
unnamed: R5.2, RESET.A
RESET: IC4.2 (/RST), IC5.1 (/RST), R6.1, RESET.K (C), S1.1 (S), ST1.B2, X1.B2, X2.B2, X3.B2, X4.B2
RW: RW.K (C), ST1.A1, X1.A1, X2.A1, X3.A1, X4.A1
VCC: J1.1, S3.2

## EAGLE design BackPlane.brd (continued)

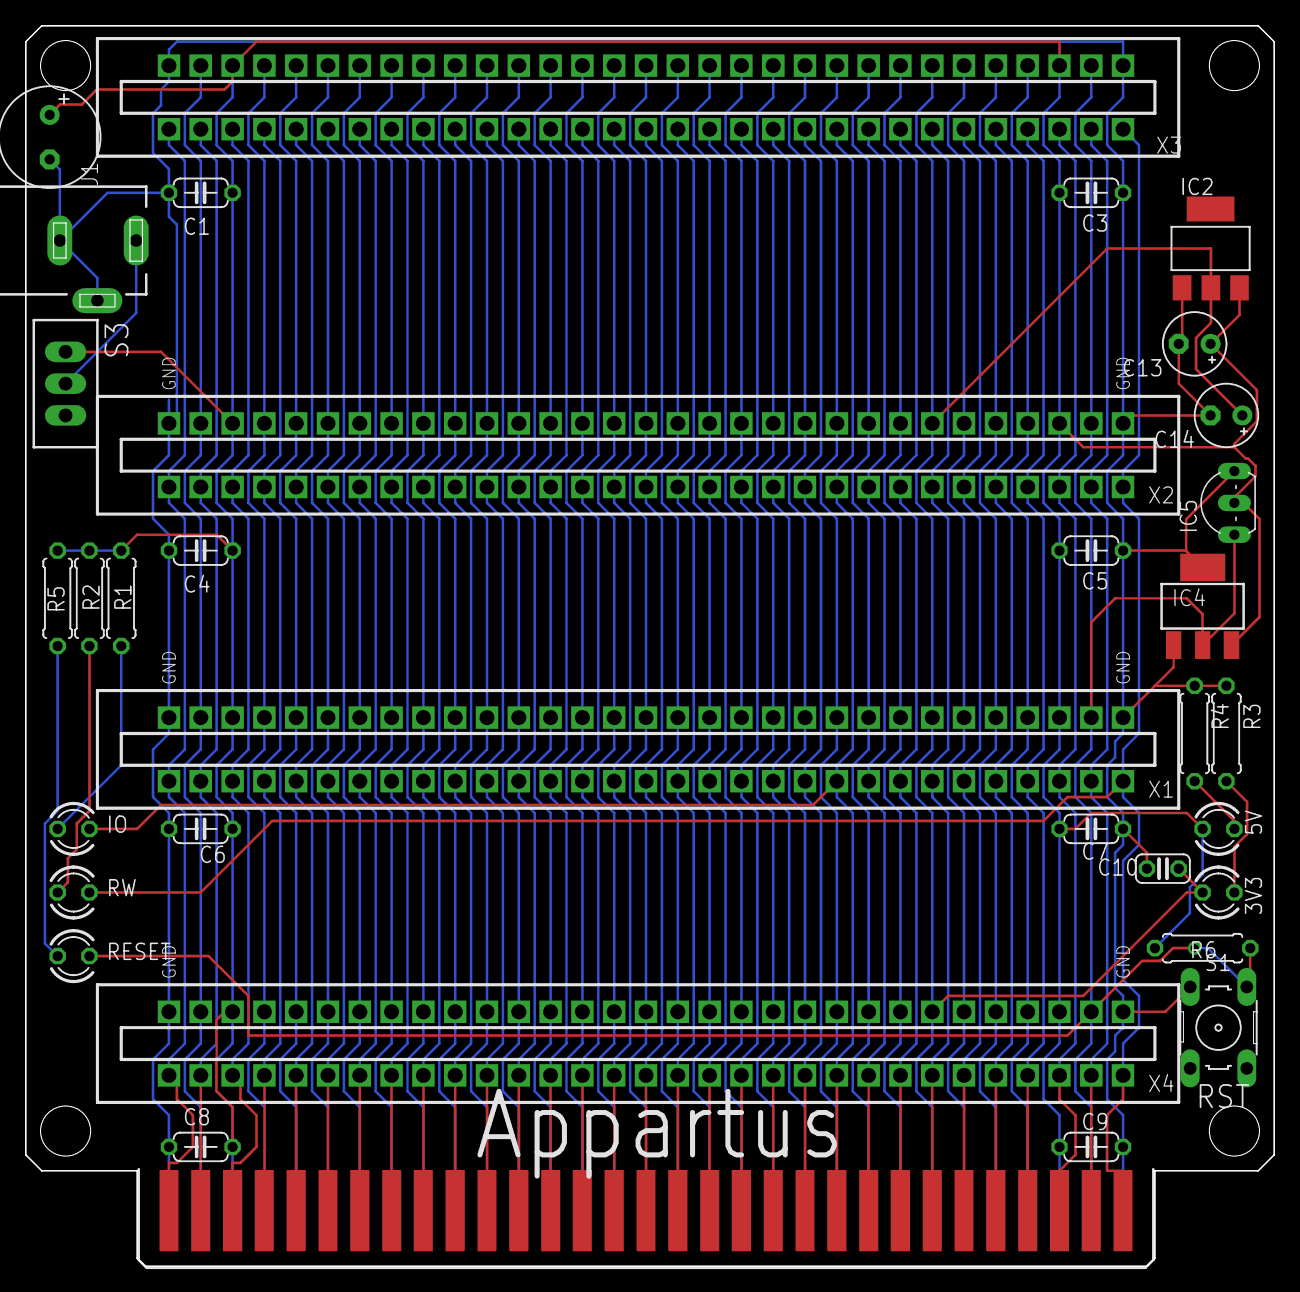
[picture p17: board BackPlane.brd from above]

Board: 2 copper layers, 99.7 x 99.1 mm, 34 parts (0 on the bottom side), 66 nets.

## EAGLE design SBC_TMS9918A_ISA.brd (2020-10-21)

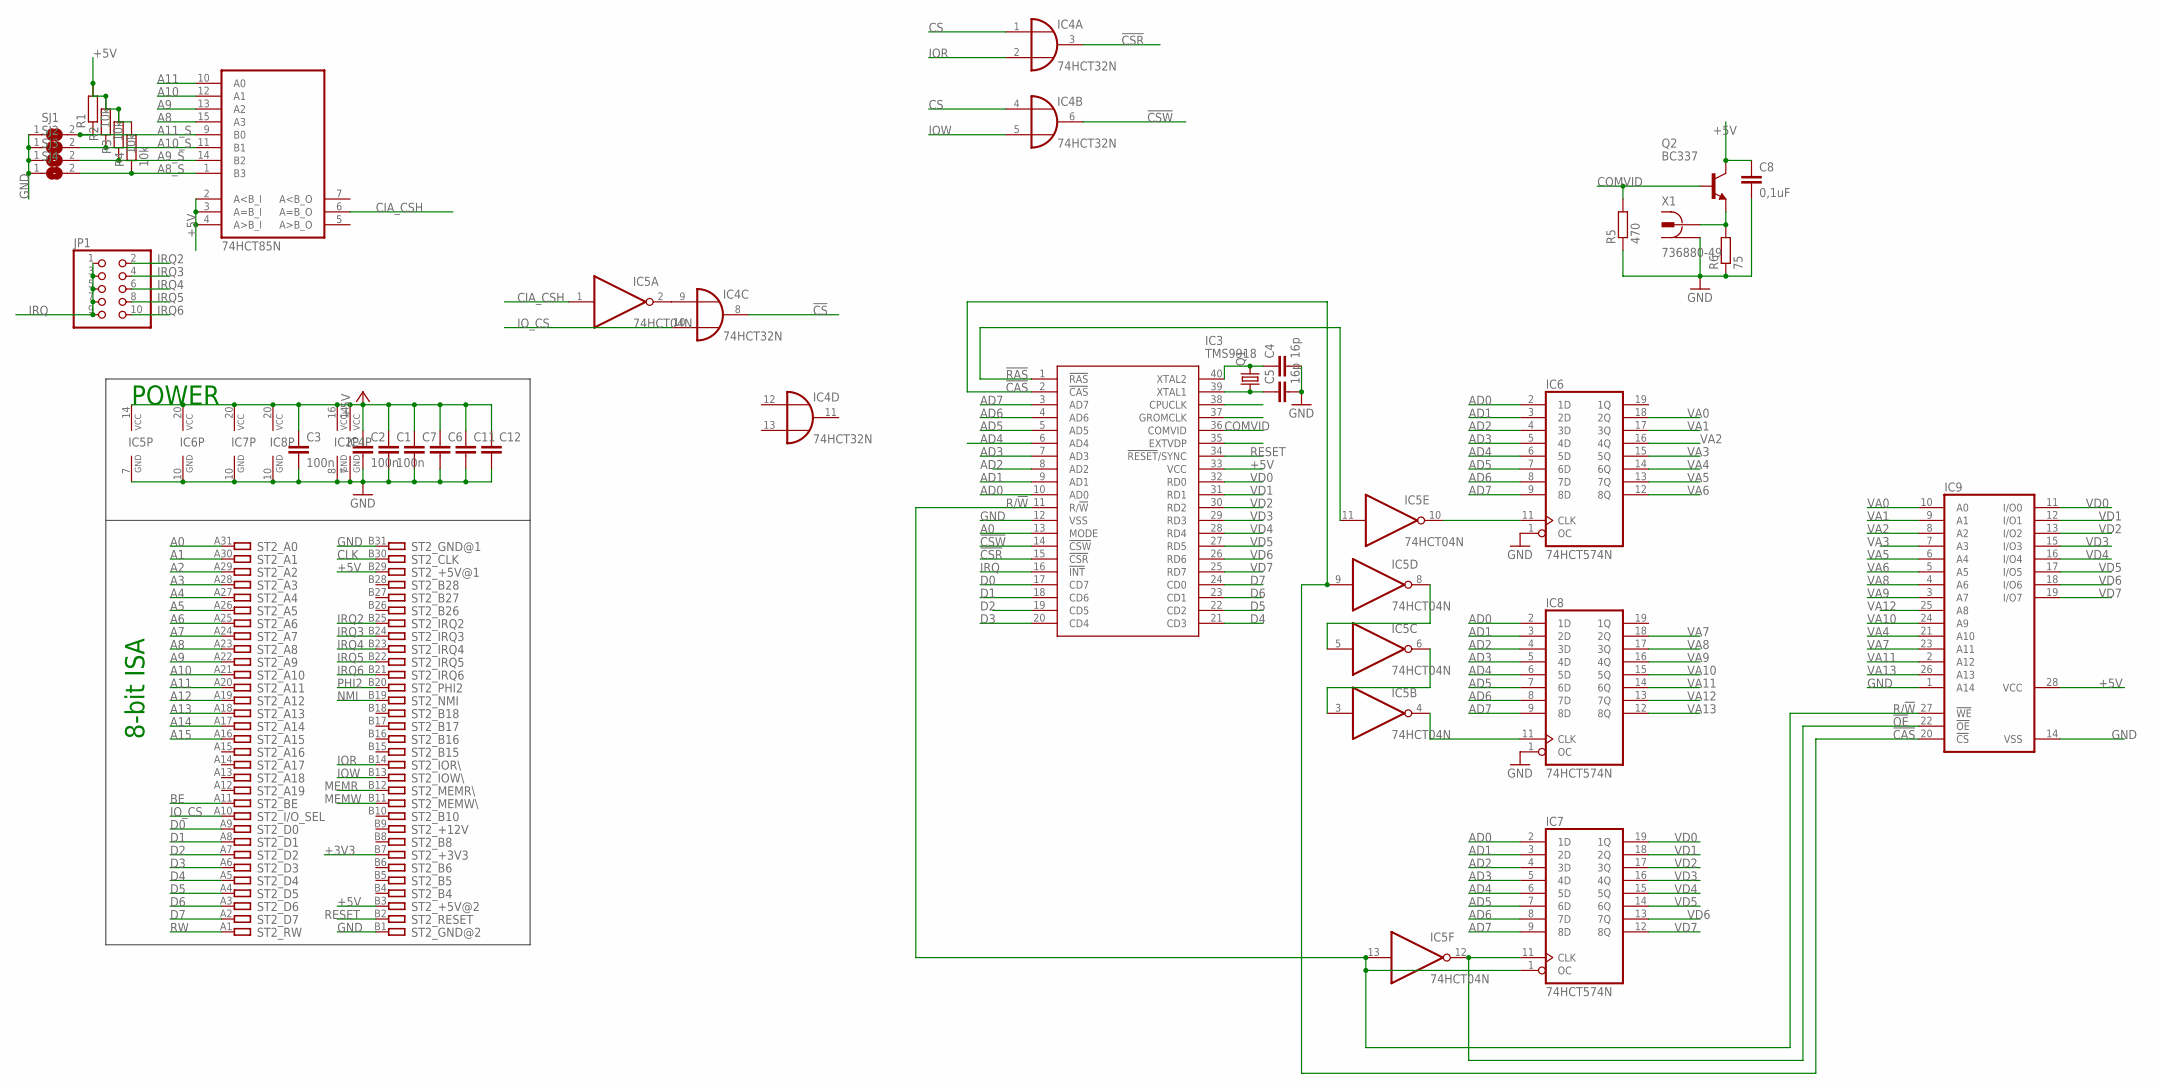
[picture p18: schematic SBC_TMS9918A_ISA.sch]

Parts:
C1, C2, C3: 100n; C050-025X075
C4, C5: 16p; C050-024X044
C6, C7, C11, C12: C-EU050-035X075; C050-035X075
C8: 0,1uF; C050-024X044
IC2: 74HCT85N; DIL16
IC3: TMS9918; DIP1524W53P254L5310H508Q40N
IC4: 74HCT32N; DIL14
IC5: 74HCT04N; DIL14
IC6, IC7, IC8: 74HCT574N; DIL20
IC9: 62256P; DIL28-6
JP1: PINHD-2X5; 2X05
Q1: CRYSTALHC49S; HC49/S
Q2: BC337; TO92
R1, R2, R3, R4: 10k; 0207/7
R5: 470; 0207/7
R6: 75; 0207/7
SJ1, SJ2, SJ3, SJ4: SJ
ST2: IBM8BIT_ISASHORT; APP_2X32_SHORT
X1: 736880-49

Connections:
!CAS: IC3.2 (!CAS), IC5.9 (I), IC9.20 (!CS)
!CS: IC4.8 (O)
!CSR: IC3.15 (!CSR), IC4.3 (O)
!CSW: IC3.14 (!CSW), IC4.6 (O)
!OE: IC5.12 (O), IC7.11 (CLK), IC9.22 (!OE)
!RAS: IC3.1 (!RAS), IC5.11 (I)
+3V3: ST2.B7
+5V: C1.1, C2.1, C3.1, C6.1, C7.1, C8.1, C11.1, C12.1, IC2.2 (A<B_I), IC2.3 (A=B_I), IC2.4 (A>B_I), IC2.16 (VCC), IC3.33 (VCC), IC4.14 (VCC), IC5.14 (VCC), IC6.20 (VCC), IC7.20 (VCC), IC8.20 (VCC), IC9.28 (VCC), Q2.3 (C), R1.2, R2.2, R3.2, R4.2, ST2.B3, ST2.B29
A0: IC3.13 (MODE), ST2.A31
A1: ST2.A30
A2: ST2.A29
A3: ST2.A28
A4: ST2.A27
A5: ST2.A26
A6: ST2.A25
A7: ST2.A24
A8: IC2.15 (A3), ST2.A23
A8_S: IC2.1 (B3), R4.1, SJ4.2
A9: IC2.13 (A2), ST2.A22
A9_S: IC2.14 (B2), R3.1, SJ3.2
A10: IC2.12 (A1), ST2.A21
A10_S: IC2.11 (B1), R2.1, SJ2.2
A11: IC2.10 (A0), ST2.A20
A11_S: IC2.9 (B0), R1.1, SJ1.2
A12: ST2.A19
A13: ST2.A18
A14: ST2.A17
A15: ST2.A16
AD0: IC3.10 (AD0), IC6.2 (1D), IC7.2 (1D), IC8.2 (1D)
AD1: IC3.9 (AD1), IC6.3 (2D), IC7.3 (2D), IC8.3 (2D)
AD2: IC3.8 (AD2), IC6.4 (3D), IC7.4 (3D), IC8.4 (3D)
AD3: IC3.7 (AD3), IC6.5 (4D), IC7.5 (4D), IC8.5 (4D)
AD4: IC3.6 (AD4), IC6.6 (5D), IC7.6 (5D), IC8.6 (5D)
AD5: IC3.5 (AD5), IC6.7 (6D), IC7.7 (6D), IC8.7 (6D)
AD6: IC3.4 (AD6), IC6.8 (7D), IC7.8 (7D), IC8.8 (7D)
AD7: IC3.3 (AD7), IC6.9 (8D), IC7.9 (8D), IC8.9 (8D)
BE: ST2.A11
CIA_CSH: IC2.6 (A=B_O), IC5.1 (I)
CLK: ST2.B30
COMVID: IC3.36 (COMVID), Q2.2 (B), R5.2
CS: IC4.1 (I0), IC4.4 (I0)
D0: IC3.17 (CD7), ST2.A9
D1: IC3.18 (CD6), ST2.A8
D2: IC3.19 (CD5), ST2.A7
D3: IC3.20 (CD4), ST2.A6
D4: IC3.21 (CD3), ST2.A5
D5: IC3.22 (CD2), ST2.A4
D6: IC3.23 (CD1), ST2.A3
D7: IC3.24 (CD0), ST2.A2
GND: C1.2, C2.2, C3.2, C4.2, C5.2, C6.2, C7.2, C8.2, C11.2, C12.2, IC2.8 (GND), IC3.12 (VSS), IC4.7 (GND), IC5.7 (GND), IC6.1 (OC), IC6.10 (GND), IC7.10 (GND), IC8.1 (OC), IC8.10 (GND), IC9.1 (A14), IC9.14 (VSS), R5.1, R6.1, SJ1.1, SJ2.1, SJ3.1, SJ4.1, ST2.B1, ST2.B31, X1.1, X1.1@1 (1), X1.1@2 (1)
IOR: IC4.2 (I1), ST2.B14
IOW: IC4.5 (I1), ST2.B13
IO_CS: IC4.10 (I1), ST2.A10
IRQ: IC3.16 (!INT), JP1.1, JP1.3, JP1.5, JP1.7, JP1.9
IRQ2: JP1.2, ST2.B25
IRQ3: JP1.4, ST2.B24
IRQ4: JP1.6, ST2.B23
IRQ5: JP1.8, ST2.B22
IRQ6: JP1.10, ST2.B21
MEMR: ST2.B12
MEMW: ST2.B11
unnamed: IC4.9 (I0), IC5.2 (O)
unnamed: Q2.1 (E), R6.2, X1.2
unnamed: IC5.10 (O), IC6.11 (CLK)
unnamed: IC5.5 (I), IC5.8 (O)
unnamed: IC5.3 (I), IC5.6 (O)
unnamed: IC5.4 (O), IC8.11 (CLK)
unnamed: C4.1, IC3.40 (XTAL2), Q1.2
unnamed: C5.1, IC3.39 (XTAL1), Q1.1
NMI: ST2.B19
PHI2: ST2.B20
R/!W: IC3.11 (R/!W), IC5.13 (I), IC7.1 (OC), IC9.27 (!WE)
RESET: IC3.34 (!RESET!/SYNC), ST2.B2
RW: ST2.A1
VA0: IC6.18 (2Q), IC9.10 (A0)
VA1: IC6.17 (3Q), IC9.9 (A1)
VA2: IC6.16 (4Q), IC9.8 (A2)
VA3: IC6.15 (5Q), IC9.7 (A3)
VA4: IC6.14 (6Q), IC9.21 (A10)
VA5: IC6.13 (7Q), IC9.6 (A4)
VA6: IC6.12 (8Q), IC9.5 (A5)
VA7: IC8.18 (2Q), IC9.23 (A11)
VA8: IC8.17 (3Q), IC9.4 (A6)
VA9: IC8.16 (4Q), IC9.3 (A7)
VA10: IC8.15 (5Q), IC9.24 (A9)
VA11: IC8.14 (6Q), IC9.2 (A12)
VA12: IC8.13 (7Q), IC9.25 (A8)
VA13: IC8.12 (8Q), IC9.26 (A13)
VD0: IC3.32 (RD0), IC7.19 (1Q), IC9.11 (I/O0)
VD1: IC3.31 (RD1), IC7.18 (2Q), IC9.12 (I/O1)
VD2: IC3.30 (RD2), IC7.17 (3Q), IC9.13 (I/O2)
VD3: IC3.29 (RD3), IC7.16 (4Q), IC9.15 (I/O3)
VD4: IC3.28 (RD4), IC7.15 (5Q), IC9.16 (I/O4)
VD5: IC3.27 (RD5), IC7.14 (6Q), IC9.17 (I/O5)
VD6: IC3.26 (RD6), IC7.13 (7Q), IC9.18 (I/O6)
VD7: IC3.25 (RD7), IC7.12 (8Q), IC9.19 (I/O7)

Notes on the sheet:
POWER
8-bit ISA


Board: 2 copper layers, 99.7 x 99.1 mm, 33 parts (0 on the bottom side), 76 nets.

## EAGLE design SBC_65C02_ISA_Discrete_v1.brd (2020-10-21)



Board: 2 copper layers, 99.7 x 99.1 mm, 46 parts (4 on the bottom side), 76 nets, no tracks yet.

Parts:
C1, C2, C3, C8, C10: 100n; C050-025X075
C4: C025-030X050
C5, C9: E3,5-8
C6, C7: C050-035X075
IC1: 74LS00N; DIL14
IC2: DIL28-6
IC3: 74HCT02N; DIL14
IC4: DS1813; SOT223
IC5: DS1813; TO-92
IC6: 74AC00N; DIL14
IC7: REG1117; SOT223
IC8: 74HCT00N; DIL14
IC9: 74HCT04N; DIL14
IC10: 74HC148N; DIL16
IC11: 74HCT574N; DIL20
IO_LED: LED5MM
IRQ_LED: LED5MM
J1: DCJ0202
JP3: 1X06/90
Q1: 1,8432MHz; HC49/S
QG2: DIL14S
R1, R2, R3, R4, R8, R9, R10: 22k; 0207/10
R5, R6, R7: 680R; 0207/10
RESET: LED5MM
ROM_1, ROM_27: 0R-JUMPA; A0R-JMP
S1: B3F-10XX
ST2: IBM8BIT
U1: W65C02SP; DIP-40
U$1: AT28C256-28DIPZIF28-6; 228-1277-00-0602J
U$2: GAL22V10; DIL28_1
U$4: R6551; DIP-28

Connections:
+3V3: C8.1, C9.+, IC7.2, ST2.B7
+5V: C1.1, C2.1, C3.1, C5.+, C6.1, C7.1, C10.1, IC1.14, IC2.28, IC3.14, IC4.3, IC5.2, IC6.14, IC7.3, IC8.14, IC9.14, IC10.16, IC11.20, J1.1, QG2.14, R1.1, R2.1, R3.1, R4.1, R5.2, R6.2, R7.2, R8.1, R9.2, R10.1, ST2.B3, ST2.B29, U1.8, U$1.28, U$4.15
A0: IC2.10, ST2.A31, U1.9, U$1.10, U$4.13
A1: IC2.9, ST2.A30, U1.10, U$1.9, U$4.14
A2: IC2.8, ST2.A29, U1.11, U$1.8
A3: IC2.7, ST2.A28, U1.12, U$1.7
A4: IC2.6, ST2.A27, U1.13, U$1.6
A5: IC2.5, ST2.A26, U1.14, U$1.5
A6: IC2.4, ST2.A25, U1.15, U$1.4
A7: IC2.3, ST2.A24, U1.16, U$1.3
A8: IC2.25, IC6.2, ST2.A23, U1.17, U$1.25
A9: IC2.24, IC6.1, ST2.A22, U1.18, U$1.24
A10: IC2.21, IC6.5, ST2.A21, U1.19, U$1.21
A11: IC2.23, IC6.4, ST2.A20, U1.20, U$1.23
A12: IC2.2, IC3.6, IC9.3, ST2.A19, U1.22, U$1.2
A13: IC2.26, IC3.5, IC9.1, ST2.A18, U1.23, U$1.26
A14: IC2.1, IC8.2, ROM_1.3, ROM_27.1, ST2.A17, U1.24
A15: IC2.20, IC8.1, ST2.A16, U1.25
ACIA_CS: IC8.8, U$4.3
ACIA_CS0: R9.1, U$4.2
BE: R10.2, ST2.A11, U1.36
CLK: QG2.8, ST2.B30, U1.37
D0: IC2.11, IC11.19, ST2.A9, U1.33, U$1.11, U$4.18
D1: IC2.12, IC11.18, ST2.A8, U1.32, U$1.12, U$4.19
D2: IC2.13, IC11.17, ST2.A7, U1.31, U$1.13, U$4.20
D3: IC2.15, IC11.16, ST2.A6, U1.30, U$1.15, U$4.21
D4: IC2.16, IC11.15, ST2.A5, U1.29, U$1.16, U$4.22
D5: IC2.17, IC11.14, ST2.A4, U1.28, U$1.17, U$4.23
D6: IC2.18, IC11.13, ST2.A3, U1.27, U$1.18, U$4.24
D7: IC2.19, IC11.12, ST2.A2, U1.26, U$1.19, U$4.25
GND: C1.2, C2.2, C3.2, C4.1, C5.-, C6.2, C7.2, IC1.7, IC2.14, IC3.7, IC4.1, IC4.4, IC5.3, IC6.7, IC8.7, IC9.7, IC10.5, IC10.8, IC11.10, J1.2, J1.3, JP3.6, QG2.7, S1.1, S1.2, ST2.B1, ST2.B31, U1.21, U$1.14, U$4.1, U$4.9, U$4.16, U$4.17
IOR: IC1.8, ST2.B14
IOW: IC1.11, ST2.B13
IO_CS: IC9.6, IC9.13, IO_LED.K, ST2.A10
IO_CS_N: IC1.10, IC1.12, IC8.10, IC9.12
IRQ: IC10.14, IRQ_LED.K, R2.2, U1.4
IRQ0: IC10.4, U$4.26
IRQ2: IC10.2, ST2.B25
IRQ3: IC10.1, ST2.B24
IRQ4: IC10.13, ST2.B23
IRQ5: IC10.12, ST2.B22
IRQ6: IC10.11, ST2.B21
MEMR: IC1.3, IC1.13, IC2.22, ST2.B12, U$1.22
MEMW: IC1.6, IC1.9, IC2.27, ST2.B11
unnamed: IC8.4, IC9.2
unnamed: IRQ_LED.A, R6.1
unnamed: IC3.11, IC6.6
unnamed: IC3.12, IC6.3
unnamed: IC8.5, IC9.4
unnamed: R5.1, RESET.A
unnamed: IC3.2, IC3.8, IC8.3
unnamed: IC3.13, IC8.9
unnamed: IC10.9, IC11.3
unnamed: IC1.5, IC9.10
unnamed: IC10.7, IC11.4
unnamed: C8.2, C9.-, C10.2, IC7.1
unnamed: IO_LED.A, R7.1
unnamed: IC3.3, IC8.6
unnamed: IC3.1, IC9.5
unnamed: IC3.4, IC3.9
unnamed: IC3.10, IC9.9
unnamed: IC10.6, IC11.5
unnamed: IC11.2, IC11.6, IC11.7, IC11.8, IC11.9
unnamed: C4.2, Q1.1, U$4.6
unnamed: Q1.2, U$4.7
NMI: R3.2, ST2.B19, U1.6
PHI2: IC1.2, IC1.4, IC11.11, ST2.B20, U1.39, U$4.27
RDY: R1.2, U1.2
RESET: IC4.2, IC5.1, R4.2, RESET.K, S1.3, S1.4, ST2.B2, U1.40, U$4.4
ROM_1: ROM_1.2, U$1.1
ROM_27: ROM_27.2, U$1.27
ROM_CS: IC9.8, U$1.20
ROM_WRITE: R8.2, ROM_1.1, ROM_27.3
RW: IC1.1, IC9.11, ST2.A1, U1.34, U$4.28
RX: JP3.2, U$4.10
TX: JP3.3, U$4.12

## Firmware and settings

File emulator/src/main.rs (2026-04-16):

/// Project65 SBC 65C02 Emulator — entry point.
///
/// Usage:
///   p65emu [OPTIONS] [ROM]
///
/// Options:
///   -s, --speed <HZ>      Initial CPU speed in Hz (default 1000000)
///   -p, --port  <PORT>    TCP serial port (default 6551, 0 = disabled)
///   -h, --help
///
/// The emulator exposes two interfaces to the ACIA serial port:
///   1. Built-in TUI terminal panel (keyboard → RX, TX → display)
///   2. TCP server — connect with PuTTY / nc / minicom to localhost:<PORT>

mod cpu;
mod bus;
mod ram;
mod rom;
mod acia;
mod via;
mod irq_latch;
mod tms9918a;
mod saa1099;
mod app;

use std::sync::{Arc, Mutex, mpsc};
use std::sync::atomic::{AtomicBool, Ordering};
use std::thread;
use std::time::{Duration, Instant};
use std::net::{TcpListener, TcpStream};
use std::io::{Read, Write};

use rodio::{OutputStream, Sink};

use clap::Parser;
use minifb::{Key, Window, WindowOptions, Scale};

use acia::AciaIo;
use app::{App, Cmd, SharedState};
use bus::{Bus, ChipFamily};
use cpu::Cpu;
use tms9918a::{WIDTH as VDP_W, HEIGHT as VDP_H};

#[derive(Parser)]
#[command(name = "p65emu", about = "Project65 SBC 65C02 Emulator")]
struct Cli {
    /// ROM binary file to load at $E000
    rom: Option<String>,

    /// CPU speed in Hz (0 = unlimited)
    #[arg(short, long, default_value_t = 1_000_000)]
    speed: u64,

    /// TCP port for virtual serial port (0 = disabled)
    #[arg(short, long, default_value_t = 6551)]
    port: u16,

    /// Adresní dekodér — rodina logických obvodů IC9/IC11
    /// Hodnoty: LS, ALS, HCT, HC, AC, ACT  (výchozí: HCT)
    #[arg(short = 'f', long = "family", default_value = "HCT")]
    family: String,

    /// Zakáže TMS9918A video okno
    #[arg(long = "no-video", default_value_t = false)]
    no_video: bool,

    /// Zakáže SAA1099 audio výstup
    #[arg(long = "no-audio", default_value_t = false)]
    no_audio: bool,
}

fn main() {
    let cli = Cli::parse();

    // ── ACIA I/O queues ───────────────────────────────────────────────────
    let acia_io = Arc::new(Mutex::new(AciaIo::default()));

    // ── Build bus and initial state ───────────────────────────────────────
    let acia = acia::Acia::new(Arc::clone(&acia_io));
    let mut bus = Bus::new(acia);

    // Set chip family (address decoder timing model)
    let family: ChipFamily = cli.family.parse().unwrap_or_else(|e| {
        eprintln!("Warning: {e}. Používám HCT.");
        ChipFamily::HCT
    });
    bus.chip_family = family;
    eprintln!("Chip family: {}  (decode delay: {} ns)",
        family.name(), bus.decode_delay_ns());

    // Load ROM if provided
    if let Some(path) = &cli.rom {
        match std::fs::read(path) {
            Ok(data) => {
                bus.rom.load(&data);
                eprintln!("Loaded ROM: {} ({} bytes)", path, data.len());
            }
            Err(e) => {
                eprintln!("Warning: could not load ROM '{}': {}", path, e);
            }
        }
    }

    let shared   = Arc::new(Mutex::new(SharedState::new(bus)));
    let (cmd_tx, cmd_rx) = mpsc::channel::<Cmd>();

    // ── TMS9918A video window thread ──────────────────────────────────────
    // Shared framebuffer: CPU thread copies VDP framebuf here after each frame.
    let vdp_fb: Arc<Mutex<Vec<u32>>> = Arc::new(Mutex::new(vec![0xFF000000u32; VDP_W * VDP_H]));
    let vdp_quit = Arc::new(AtomicBool::new(false));
    if !cli.no_video {
        let fb_clone    = Arc::clone(&vdp_fb);
        let quit_clone  = Arc::clone(&vdp_quit);
        thread::Builder::new().name("vdp-window".into()).spawn(move || {
            video_window_thread(fb_clone, quit_clone);
        }).unwrap();
    }

    // ── SAA1099 audio thread ──────────────────────────────────────────────
    if !cli.no_audio {
        let sh_audio = Arc::clone(&shared);
        thread::Builder::new().name("saa-audio".into()).spawn(move || {
            saa_audio_thread(sh_audio);
        }).unwrap();
    }

    // ── TCP virtual serial port thread ────────────────────────────────────
    if cli.port != 0 {
        let io_clone = Arc::clone(&acia_io);
        let port = cli.port;
        thread::Builder::new().name("tcp-serial".into()).spawn(move || {
            tcp_serial_server(io_clone, port);
        }).unwrap();
    }

    // ── CPU emulation thread ──────────────────────────────────────────────
    {
        let shared_cpu = Arc::clone(&shared);
        let fb_cpu     = Arc::clone(&vdp_fb);
        thread::Builder::new().name("cpu".into()).spawn(move || {
            cpu_thread(shared_cpu, cmd_rx, cli.speed, fb_cpu);
        }).unwrap();
    }

    // ── TUI (main thread) ─────────────────────────────────────────────────
    {
        let mut lock = shared.lock().unwrap();
        lock.speed_hz = cli.speed;
    }

    let mut app = App::new(Arc::clone(&shared), Arc::clone(&acia_io), cmd_tx.clone());
    app.speed_hz = cli.speed;

    if let Err(e) = app::run(&mut app) {
        eprintln!("TUI error: {}", e);
    }

    // Signal VDP window and CPU thread to quit
    vdp_quit.store(true, Ordering::Relaxed);
    let _ = cmd_tx.send(Cmd::Quit);
}

// ── CPU thread ────────────────────────────────────────────────────────────────

fn cpu_thread(
    shared: Arc<Mutex<SharedState>>,
    cmd_rx: mpsc::Receiver<Cmd>,
    initial_speed: u64,
    vdp_fb: Arc<Mutex<Vec<u32>>>,
) {
    let mut cpu = Cpu::new();
    let mut speed_hz = initial_speed;
    let mut running = false;
    let mut quit = false;

    // Reset CPU on startup
    {
        let mut st = shared.lock().unwrap();
        st.speed_hz = speed_hz;
        cpu.reset(&mut st.bus);
        st.cpu = cpu.snapshot();
    }

    let mut cycle_budget: i64 = 0;
    let mut last_tick = Instant::now();

    while !quit {
        // ── Drain commands ────────────────────────────────────────────────
        loop {
            match cmd_rx.try_recv() {
                Ok(cmd) => match cmd {
                    Cmd::Run   => running = true,
                    Cmd::Pause => running = false,
                    Cmd::Step  => {
                        // Single step even if paused
                        let mut st = shared.lock().unwrap();
                        let (nmi, irq) = st.bus.tick(1);
                        cpu.poll_interrupts(&mut st.bus, nmi, irq);
                        cpu.step(&mut st.bus);
                        st.cpu = cpu.snapshot();
                        st.nmi = nmi;
                        st.irq = irq;
                        running = false;
                    }
                    Cmd::Reset => {
                        let mut st = shared.lock().unwrap();
                        cpu.reset(&mut st.bus);
                        st.cpu = cpu.snapshot();
                    }
                    Cmd::SetSpeed(hz) => {
                        speed_hz = hz;
                        let mut st = shared.lock().unwrap();
                        st.speed_hz = hz;
                        cycle_budget = 0;
                    }
                    Cmd::LoadAt { data, addr, reset } => {
                        let mut st = shared.lock().unwrap();
                        if addr >= 0xE000 {
                            // Load into ROM struct (writes to ROM are ignored by bus)
                            st.bus.rom.load(&data);
                        } else {
                            // Write into RAM through normal bus write path
                            for (i, &b) in data.iter().enumerate() {
                                let target = addr.wrapping_add(i as u16);
                                st.bus.write(target, b);
                            }
                        }
                        if reset {
                            cpu.reset(&mut st.bus);
                        }
                        st.cpu = cpu.snapshot();
                    }
                    Cmd::SetReg { field, val } => {
                        match field {
                            0 => cpu.a  = val as u8,
                            1 => cpu.x  = val as u8,
                            2 => cpu.y  = val as u8,
                            3 => cpu.sp = val as u8,
                            4 => cpu.pc = val,
                            5 => cpu.p  = (val as u8) | 0x20, // U flag always set
                            _ => {}
                        }
                        let mut st = shared.lock().unwrap();
                        st.cpu = cpu.snapshot();
                    }
                    Cmd::Quit => { quit = true; break; }
                },
                Err(mpsc::TryRecvError::Empty) => break,
                Err(mpsc::TryRecvError::Disconnected) => { quit = true; break; }
            }
        }

        if quit { break; }

        if running {
            let elapsed = last_tick.elapsed();
            last_tick = Instant::now();

            // How many cycles should we execute this slice?
            let slice_cycles = if speed_hz == u64::MAX {
                100_000i64 // unlimited: run in big chunks
            } else {
                let c = (speed_hz as f64 * elapsed.as_secs_f64()) as i64;
                c.min(100_000) // cap per slice to stay responsive
            };

            cycle_budget += slice_cycles;

            // Execute cycles
            if cycle_budget > 0 {
                let mut st = shared.lock().unwrap();
                let mut executed = 0i64;

                while executed < cycle_budget && !cpu.halted {
                    let (nmi, irq) = st.bus.tick(1);
                    cpu.poll_interrupts(&mut st.bus, nmi, irq);
                    let c = cpu.step(&mut st.bus) as i64;
                    executed += c;
                    st.nmi = nmi;
                    st.irq = irq;
                }

                cycle_budget -= executed;
                if cycle_budget > 200_000 { cycle_budget = 0; } // prevent runaway

                st.cpu = cpu.snapshot();
                st.running = true;

                // Copy VDP framebuffer if a new frame was rendered
                if st.bus.vdp.frame_dirty {
                    st.bus.vdp.frame_dirty = false;
                    if let Ok(mut fb) = vdp_fb.try_lock() {
                        fb.copy_from_slice(&st.bus.vdp.framebuf);
                    }
                }
            }

            // Short sleep to yield to other threads
            if speed_hz != u64::MAX {
                thread::sleep(Duration::from_micros(500));
            } else {
                thread::yield_now();
            }
        } else {
            // Paused — just sleep
            last_tick = Instant::now();
            {
                let mut st = shared.lock().unwrap();
                st.running = false;
            }
            thread::sleep(Duration::from_millis(10));
        }
    }
}

// ── TCP virtual serial port ───────────────────────────────────────────────────

fn tcp_serial_server(io: Arc<Mutex<AciaIo>>, port: u16) {
    let addr = format!("127.0.0.1:{}", port);
    let listener = match TcpListener::bind(&addr) {
        Ok(l) => { eprintln!("[serial] Listening on {}", addr); l }
        Err(e) => { eprintln!("[serial] Could not bind {}: {}", addr, e); return; }
    };

    for stream in listener.incoming() {
        match stream {
            Ok(stream) => {
                eprintln!("[serial] Client connected: {}", stream.peer_addr().unwrap());
                let io2 = Arc::clone(&io);
                thread::spawn(move || { handle_tcp_client(stream, io2); });
            }
            Err(_) => break,
        }
    }
}

fn handle_tcp_client(mut stream: TcpStream, io: Arc<Mutex<AciaIo>>) {
    stream.set_nonblocking(true).ok();
    let mut rx_buf = [0u8; 64];

    loop {
        // Forward TCP → ACIA RX
        match stream.read(&mut rx_buf) {
            Ok(0) => break, // disconnected
            Ok(n) => {
                if let Ok(mut io) = io.lock() {
                    for &b in &rx_buf[..n] { io.rx_buf.push_back(b); }
                }
            }
            Err(ref e) if e.kind() == std::io::ErrorKind::WouldBlock => {}
            Err(_) => break,
        }

        // Forward ACIA TX → TCP
        let bytes: Vec<u8> = {
            if let Ok(mut io) = io.try_lock() {
                io.tx_buf.drain(..).collect()
            } else { vec![] }
        };
        if !bytes.is_empty() {
            if stream.write_all(&bytes).is_err() { break; }
        }

        thread::sleep(Duration::from_millis(2));
    }
    eprintln!("[serial] Client disconnected.");
}

// ── TMS9918A video window ─────────────────────────────────────────────────────

fn video_window_thread(fb: Arc<Mutex<Vec<u32>>>, quit: Arc<AtomicBool>) {
    let mut window = match Window::new(
        "Project65 — TMS9918A Display",
        VDP_W, VDP_H,
        WindowOptions {
            scale: Scale::X2,
            resize: false,
            ..WindowOptions::default()
        },
    ) {
        Ok(w)  => w,
        Err(e) => { eprintln!("[vdp] Cannot open window: {}", e); return; }
    };

    // Limit to ~60 fps
    window.limit_update_rate(Some(std::time::Duration::from_micros(16_667)));

    let mut local_fb = vec![0xFF000000u32; VDP_W * VDP_H];

    while window.is_open() && !window.is_key_down(Key::Escape) {
        // Zavři okno když TUI skončí (quit flag nastaven po app::run)
        if quit.load(Ordering::Relaxed) { break; }

        // Copy latest framebuffer
        if let Ok(src) = fb.try_lock() {
            local_fb.copy_from_slice(&src);
        }

        window.update_with_buffer(&local_fb, VDP_W, VDP_H).unwrap_or(());
    }
}

// ── SAA1099 audio (square wave synthesis) ────────────────────────────────────

struct SaaAudioSource {
    shared:      Arc<Mutex<SharedState>>,
    sample_rate: u32,
    phase:       [f32; 6],
}

impl Iterator for SaaAudioSource {
    type Item = f32;

    fn next(&mut self) -> Option<f32> {
        let mut out = 0.0f32;

        if let Ok(st) = self.shared.try_lock() {
            let saa = &st.bus.saa;
            if saa.enabled {
                for ch in 0..6usize {
                    if saa.channel_enabled(ch) {
                        let freq = saa.channel_freq_hz(ch);
                        if freq > 16.0 && freq < 20_000.0 {
                            self.phase[ch] += freq / self.sample_rate as f32;
                            if self.phase[ch] >= 1.0 { self.phase[ch] -= 1.0; }
                            // square wave
                            let wave = if self.phase[ch] < 0.5 { 1.0f32 } else { -1.0f32 };
                            // amplitude: [3:0]=left nibble, [7:4]=right nibble
                            let amp_l = (saa.amplitude[ch] & 0x0F) as f32 / 15.0;
                            let amp_r = (saa.amplitude[ch] >> 4) as f32 / 15.0;
                            out += wave * (amp_l + amp_r) * 0.5 / 6.0;
                        }
                    }
                }
            } else {
                // Chip disabled — decay phases
                for ph in self.phase.iter_mut() { *ph = 0.0; }
            }
        }

        Some(out.clamp(-1.0, 1.0))
    }
}

impl rodio::Source for SaaAudioSource {
    fn current_frame_len(&self) -> Option<usize>  { None }
    fn channels(&self)          -> u16              { 1 }
    fn sample_rate(&self)       -> u32              { self.sample_rate }
    fn total_duration(&self)    -> Option<Duration> { None }
}

fn saa_audio_thread(shared: Arc<Mutex<SharedState>>) {
    let (_stream, stream_handle) = match OutputStream::try_default() {
        Ok(s)  => s,
        Err(e) => { eprintln!("[audio] Nelze otevřít audio zařízení: {}", e); return; }
    };
    let sink = match Sink::try_new(&stream_handle) {
        Ok(s)  => s,
        Err(e) => { eprintln!("[audio] Nelze vytvořit audio sink: {}", e); return; }
    };
    sink.set_volume(0.5);
    sink.append(SaaAudioSource {
        shared,
        sample_rate: 44_100,
        phase: [0.0f32; 6],
    });
    sink.sleep_until_end(); // blokuje vlákno — Source je nekonečný iterátor
}

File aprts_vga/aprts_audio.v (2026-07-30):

// =============================================================
// APRTS_AUDIO - Multi-Channel Audio Synthesizer & ADSR Controller
// =============================================================
// Features a 4-channel mixed stereo audio generator with:
// - ADSR Envelope Generators for each channel.
// - DDS Phase Accumulators (Square, Triangle, Sawtooth, Sine, Trapezoid).
// - Serial I2S shift register transmitter for PCM5102A.
// =============================================================

module aprts_audio (
    input clk,
    input reset,

    // CPU Register Interface
    input write_en,
    input [3:0] lv_addr,
    input [7:0] lv_data,
    output [7:0] audio_read_val,

    // PCM5102A Interface
    output        pcm_bck,
    output        pcm_din,
    output        pcm_lrck,
    output        pcm_sck
);

    // Audio registers (4 channels)
    reg [4:0] aud_addr      = 5'h00;
    reg [7:0] reg_freq_lo_0 = 8'h00;
    reg [7:0] reg_freq_hi_0 = 8'h00;
    reg [7:0] reg_vol_0     = 8'h00;
    reg [7:0] reg_freq_lo_1 = 8'h00;
    reg [7:0] reg_freq_hi_1 = 8'h00;
    reg [7:0] reg_vol_1     = 8'h00;
    reg [7:0] reg_freq_lo_2 = 8'h00;
    reg [7:0] reg_freq_hi_2 = 8'h00;
    reg [7:0] reg_vol_2     = 8'h00;
    reg [7:0] reg_freq_lo_3 = 8'h00;
    reg [7:0] reg_freq_hi_3 = 8'h00;
    reg [7:0] reg_vol_3     = 8'h00;
    reg [7:0] reg_ctrl_0    = 8'h00;
    reg [7:0] reg_ctrl_1    = 8'h00;
    reg [7:0] reg_ctrl_2    = 8'h00;
    reg [7:0] reg_ctrl_3    = 8'h00;
    reg [7:0] reg_adsr_ad_0 = 8'h00;
    reg [7:0] reg_adsr_sr_0 = 8'h00;
    reg [7:0] reg_adsr_ad_1 = 8'h00;
    reg [7:0] reg_adsr_sr_1 = 8'h00;
    reg [7:0] reg_adsr_ad_2 = 8'h00;
    reg [7:0] reg_adsr_sr_2 = 8'h00;
    reg [7:0] reg_adsr_ad_3 = 8'h00;
    reg [7:0] reg_adsr_sr_3 = 8'h00;

    // DDS synthesis signals
    reg [8:0] audio_div     = 9'd0;
    reg [15:0] phase_acc_0  = 16'd0;
    reg [15:0] phase_acc_1  = 16'd0;
    reg [15:0] phase_acc_2  = 16'd0;
    reg [15:0] phase_acc_3  = 16'd0;
    reg pcm_din_r           = 1'b0;

    // CPU registers write/read logic
    always @(posedge clk) begin
        if (reset) begin
            aud_addr       <= 5'h00;
            reg_freq_lo_0  <= 8'h00;
            reg_freq_hi_0  <= 8'h00;
            reg_vol_0      <= 8'h00;
            reg_freq_lo_1  <= 8'h00;
            reg_freq_hi_1  <= 8'h00;
            reg_vol_1      <= 8'h00;
            reg_freq_lo_2  <= 8'h00;
            reg_freq_hi_2  <= 8'h00;
            reg_vol_2      <= 8'h00;
            reg_freq_lo_3  <= 8'h00;
            reg_freq_hi_3  <= 8'h00;
            reg_vol_3      <= 8'h00;
            reg_ctrl_0     <= 8'h00;
            reg_ctrl_1     <= 8'h00;
            reg_ctrl_2     <= 8'h00;
            reg_ctrl_3     <= 8'h00;
            reg_adsr_ad_0  <= 8'h00;
            reg_adsr_sr_0  <= 8'h00;
            reg_adsr_ad_1  <= 8'h00;
            reg_adsr_sr_1  <= 8'h00;
            reg_adsr_ad_2  <= 8'h00;
            reg_adsr_sr_2  <= 8'h00;
            reg_adsr_ad_3  <= 8'h00;
            reg_adsr_sr_3  <= 8'h00;
        end else if (write_en) begin
            if (lv_addr == 4'h5) begin
                aud_addr <= lv_data[4:0];
            end else if (lv_addr == 4'h6) begin
                case (aud_addr)
                    5'h00: reg_freq_lo_0 <= lv_data;
                    5'h01: reg_freq_hi_0 <= lv_data;
                    5'h02: reg_vol_0     <= lv_data;
                    5'h03: reg_freq_lo_1 <= lv_data;
                    5'h04: reg_freq_hi_1 <= lv_data;
                    5'h05: reg_vol_1     <= lv_data;
                    5'h06: reg_freq_lo_2 <= lv_data;
                    5'h07: reg_freq_hi_2 <= lv_data;
                    5'h08: reg_vol_2     <= lv_data;
                    5'h09: reg_freq_lo_3 <= lv_data;
                    5'h0A: reg_freq_hi_3 <= lv_data;
                    5'h0B: reg_vol_3     <= lv_data;
                    5'h0C: reg_ctrl_0    <= lv_data;
                    5'h0D: reg_ctrl_1    <= lv_data;
                    5'h0E: reg_ctrl_2    <= lv_data;
                    5'h0F: reg_ctrl_3    <= lv_data;
                    5'h10: reg_adsr_ad_0 <= lv_data;
                    5'h11: reg_adsr_sr_0 <= lv_data;
                    5'h12: reg_adsr_ad_1 <= lv_data;
                    5'h13: reg_adsr_sr_1 <= lv_data;
                    5'h14: reg_adsr_ad_2 <= lv_data;
                    5'h15: reg_adsr_sr_2 <= lv_data;
                    5'h16: reg_adsr_ad_3 <= lv_data;
                    5'h17: reg_adsr_sr_3 <= lv_data;
                    default: ;
                endcase
                // Auto-increment selector index
                if (aud_addr < 5'h17) begin
                    aud_addr <= aud_addr + 5'd1;
                end else begin
                    aud_addr <= 5'h00;
                end
            end
        end
    end

    reg [7:0] internal_read_val;
    always @(*) begin
        if (lv_addr == 4'h5) begin
            internal_read_val = {3'b0, aud_addr};
        end else if (lv_addr == 4'h6) begin
            case (aud_addr)
                5'h00: internal_read_val = reg_freq_lo_0;
                5'h01: internal_read_val = reg_freq_hi_0;
                5'h02: internal_read_val = reg_vol_0;
                5'h03: internal_read_val = reg_freq_lo_1;
                5'h04: internal_read_val = reg_freq_hi_1;
                5'h05: internal_read_val = reg_vol_1;
                5'h06: internal_read_val = reg_freq_lo_2;
                5'h07: internal_read_val = reg_freq_hi_2;
                5'h08: internal_read_val = reg_vol_2;
                5'h09: internal_read_val = reg_freq_lo_3;
                5'h0A: internal_read_val = reg_freq_hi_3;
                5'h0B: internal_read_val = reg_vol_3;
                5'h0C: internal_read_val = reg_ctrl_0;
                5'h0D: internal_read_val = reg_ctrl_1;
                5'h0E: internal_read_val = reg_ctrl_2;
                5'h0F: internal_read_val = reg_ctrl_3;
                5'h10: internal_read_val = reg_adsr_ad_0;
                5'h11: internal_read_val = reg_adsr_sr_0;
                5'h12: internal_read_val = reg_adsr_ad_1;
                5'h13: internal_read_val = reg_adsr_sr_1;
                5'h14: internal_read_val = reg_adsr_ad_2;
                5'h15: internal_read_val = reg_adsr_sr_2;
                5'h16: internal_read_val = reg_adsr_ad_3;
                5'h17: internal_read_val = reg_adsr_sr_3;
                default: internal_read_val = 8'h00;
            endcase
        end else begin
            internal_read_val = 8'h00;
        end
    end
    assign audio_read_val = internal_read_val;

    // Master I2S clock divider
    always @(posedge clk) begin
        if (reset) begin
            audio_div <= 9'd0;
        end else begin
            audio_div <= audio_div + 9'd1;
        end
    end
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

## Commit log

2021-12-22 New version
    9-1-3
    [APP.cfg, APP_RAM_DISK.cfg, APP_ROM_DISK.cfg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]
2026-04-13 Přidání minimalního bootloaderu a souvisejících skriptů pro kompilaci
    [MIN_ROM.cfg]
2026-04-13 Add component list for SBC 65C02 IRQ BigBoard v10-2-1
    [SBC_65C02_IRQ_BigBoard_v10-2-1.csv]
2026-04-13 Add Intel HEX loader and RAM test functionality
    - Updated build_minimal.bat to include ihex.asm in the build process.
    - Modified jumptable.asm to adjust reset and interrupt vectors.
    - Enhanced main_min.c to support loading Intel HEX files and added corresponding user prompts.
    - Implemented ihex.asm for parsing and loading Intel HEX format data into RAM.
    - Created ramtest.asm for testing RAM functionality with various patterns and address checks.
    - Added bin2hex.py script to convert binary output to Intel HEX format.
    - Introduced build_ramtest.bat for building the RAM test program.
    - Configured ramtest.cfg for linker settings specific to the RAM test.
    - Added ihex.h header file for the Intel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
    [ramtest.cfg]
2026-04-16 Implement core emulator components: IRQ latch, RAM, ROM, and VIA
    - Added `irq_latch.rs` to manage IRQ priority and acknowledge mechanisms.
    - Introduced `ram.rs` for generic RAM handling with read/write capabilities.
    - Created `rom.rs` to handle 8 KB read-only memory with binary loading.
    - Developed `via.rs` for W65C22 VIA emulation, including timer and interrupt management.
    - Established `main.rs` as the entry point for the emulator, integrating components and TCP serial communication.
2026-04-16 Add chiptest configuration and jump table, implement SAA1099 and TMS9918A emulation
    - Created `chiptest.cfg` for linker configuration of the chip test program.
    - Added `jumptable.inc65` for ROM jump table addresses to facilitate calling ROM routines.
    - Implemented `Saa1099` sound generator emulation in `saa1099.rs`, including bus interface and register handling.
    - Developed `Tms9918a` video display processor emulation in `tms9918a.rs`, covering bus interface, rendering, and IRQ handling.
    [chiptest.cfg]
2026-04-16 Add RAMDisk filesystem and interactive shell to AppartusOS
    - Implemented `appartus_ramdisk.asm` for RAMDisk functionality including initialization, file management, and memory operations.
    - Created `appartus_shell.asm` to provide an interactive shell with commands for file operations, memory management, and system control.
    - Introduced `appartus_zp.asm` for zero page allocations to optimize memory usage for OS operations.
    - Enhanced command handling in the shell for loading, saving, deleting, and running files from the RAMDisk.
    - Added string handling and parsing utilities for command input processing.
    [appartus_os.cfg]
2026-04-17 Optimize BASIC interpreter flow and fix stack handling in line storage
    [appartus_basic.asm]
2026-04-17 Add new schematic for SBC 65C02 IRQ BigBoard v10-2-1
    [EXP_GameDuino_V1.brd, EXP_GameDuino_V1.sch, EXP_TMS9918A_V1.brd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]
2026-04-17 Odstranění nepotřebných souborů a přidání nového příkazu pro grep do nastavení
    [JumpTable.xls, MemoryMap.xls]
2026-04-18 Add memory monitor and VERA detection test tools
    - Implemented `mem_mon.asm`, a memory monitor inspired by MS-DOS DEBUG, allowing memory dumping and writing.
    - Added `vera_test.asm` to test the presence of the VERA chip in the system, verifying register read/write functionality.
    - Generated binary, hex, and object files for both tools.
    - Included assembly instructions for building and using the tools in AppartusOS.
2026-04-22 Add new tools for FPGA flashing and VDP font definition
    - Introduced `espi_update_fpga.py` for SPI command handling and flash programming.
    - Added `build.bat` for building the Vera test project.
    - Included `font.h` containing the VDP character set definitions for the BBC-128 homebrew computer.
    - Updated `vera_test.o` binary file to reflect changes.
2026-04-22 Add preliminary documentation for VERA Programmer's Reference
    This commit introduces the VERA Programmer's Reference document, detailing the architecture and functionality of the Versatile Embedded Retro Adapter (VERA). The documentation includes information on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
2026-04-22 Add preliminary documentation for VERA Programmer's Reference
    - Introduced a new markdown file `Firmware/vera.md` detailing the VERSatile Embedded Retro Adapter (VERA).
    - Documented features including video generation, sound capabilities, SPI controller, and memory layout.
    - Included comprehensive descriptions of registers, VRAM access, display composer, layer configurations, sprite attributes, and audio functionalities.
    - Added tables for register definitions, VRAM address space layout, and audio data formats.
    - Emphasized initialization requirements and provided examples for usage.
2026-07-18 Add VGA demo module with CPU interface and SRAM integration
    - Implemented VGA output generation for 640x480 resolution at 60 Hz.
    - Added support for bitmap and text modes with corresponding memory mapping.
    - Integrated SRAM interface for video RAM and palette RAM management.
    - Included CPU control registers for memory read/write operations.
    - Added debug overlay functionality for monitoring CPU interactions.
    - Implemented splash screen generation for initial display.
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2026-07-30 Add audio synthesizer, SRAM controller, VGA timing, and video generation modules
    - Implemented a multi-channel audio synthesizer with ADSR control and I2S output in `aprt_audio.v`.
    - Created an external SRAM controller to manage memory access and clear operations in `sram_controller.v`.
    - Developed a VGA timing generator for 640x480 @ 60Hz display in `vga_timing.v`.
    - Added a VGA video generator for text and graphics rendering with internal font RAM in `vga_video_gen.v`.
    - Updated audio register addresses in `audio.inc` for correct memory mapping.
    [aprts_audio.v]

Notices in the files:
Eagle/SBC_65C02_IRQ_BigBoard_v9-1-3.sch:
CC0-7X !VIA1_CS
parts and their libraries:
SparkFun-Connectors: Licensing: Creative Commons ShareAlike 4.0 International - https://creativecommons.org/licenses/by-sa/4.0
